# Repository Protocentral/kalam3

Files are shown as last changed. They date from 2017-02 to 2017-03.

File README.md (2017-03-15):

# ProtoCentral Kalam v3 IOT platform

ProtoCentral Kalam v3 is our newest IOT platform based on the ESP8266 Wi-Fi SoC. It's easy-to-use, low cost and easily scalable. 

IoT is now made easy with quick plug-and-play functionality in both hardware and software. Based on the popular ESP8266 Wi-Fi SoC from Espressif, this board contains everything required, right out of the box.

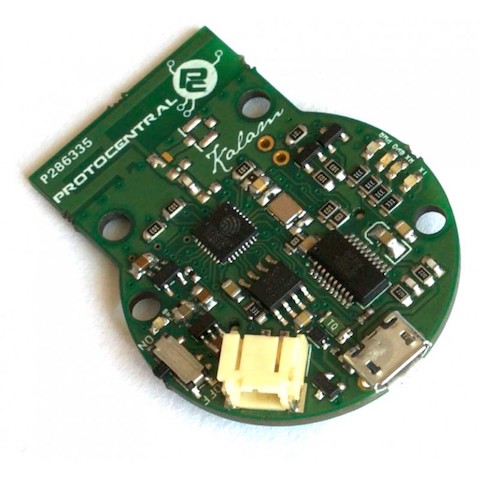
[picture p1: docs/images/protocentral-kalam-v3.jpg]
Kalam v3


Features
--------
* ESP8266EX WiFi System-on-Chip (SoC) with ARM Cortex M3 microcontroller
* On-board 2.4 GHz PCB antenna
* FTDI-based USB-UART interface with microUSB connector
* Fully compatible with the Arduino IDE
* Single Li-Ion battery powered
* On-board battery charger
* 31-pin Hirose DF-9 connector on the back for expansion

Repository Contents
-------------------
* **/hardware** - All Eagle design files (.brd, .sch)
* **/libraries** - Arduino libraries and example code
* **/docs** - Additional Documentation

Board Overview
--------------
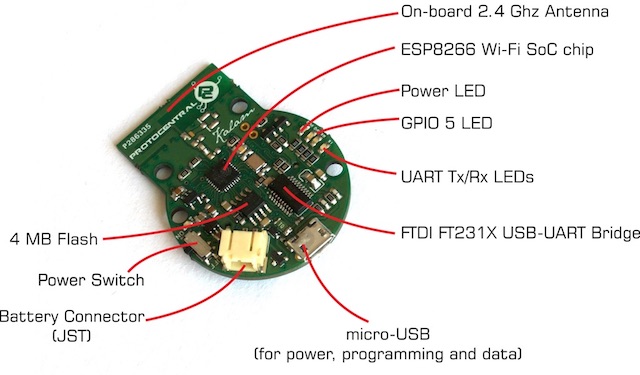
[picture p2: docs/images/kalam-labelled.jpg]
Kalam labelled


Kalam Starter Kit
---------
[Kalam Starter Kit Documentation](docs/starter_kit/README.md)

Getting Started with Kalam
--------------------------

Connect the GPIO expander cap to the Kalam V3 by stacking it on top.Now that the setup is complete,the setup needs to be powered up.Attach a Li-poly battery to the Kalam v2 Iot board.Control the power using the on/off switch

How to setup Arduino support for Kalam (using Sparkfun thing Dev)
---------------------------------------------------
Kalam is powered by the Sparkfun's board support file.The first thing you will need to do is to download the latest release of the Arduino IDE. You will need to be using version 1.6.4 or higher. 
After you have downloaded and installed v1.6.4, you will need to start the IDE and navigate to the Preferences menu.
Sparkfun's  JSON url for ESP8266 board is - https://raw.githubusercontent.com/sparkfun/Arduino_Boards/master/IDE_Board_Manager/package_sparkfun_index.json

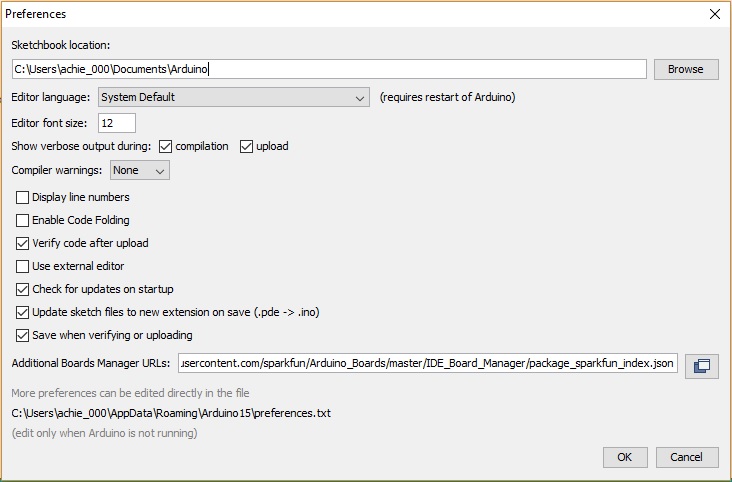
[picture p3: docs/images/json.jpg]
Json


* Click Ok to close and save the preferences
* Then click Tools > Board > Board Manager
* You should find Sparkfun ESP8266 boards listed in the Board Manager window.

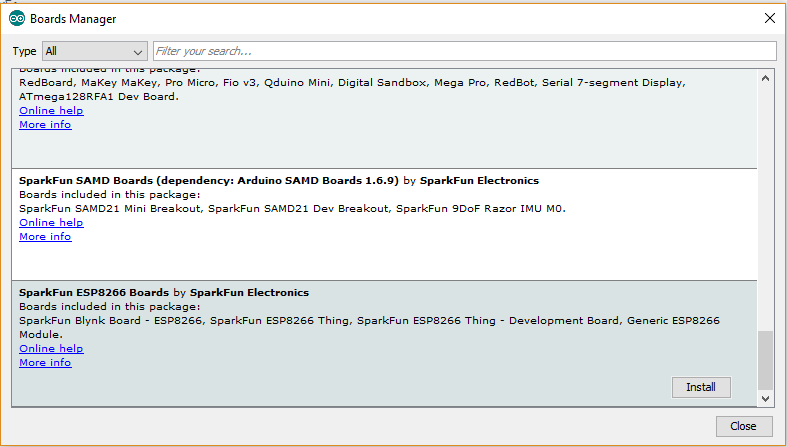
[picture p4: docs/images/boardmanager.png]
board_manager
 
 
*	Press the “Install” button on the chosen ESP8266 category.The download process will begin
* Reboot Arduino and look under Tools > Boards and you should see the addition of the Sparkfun boards in your board list.
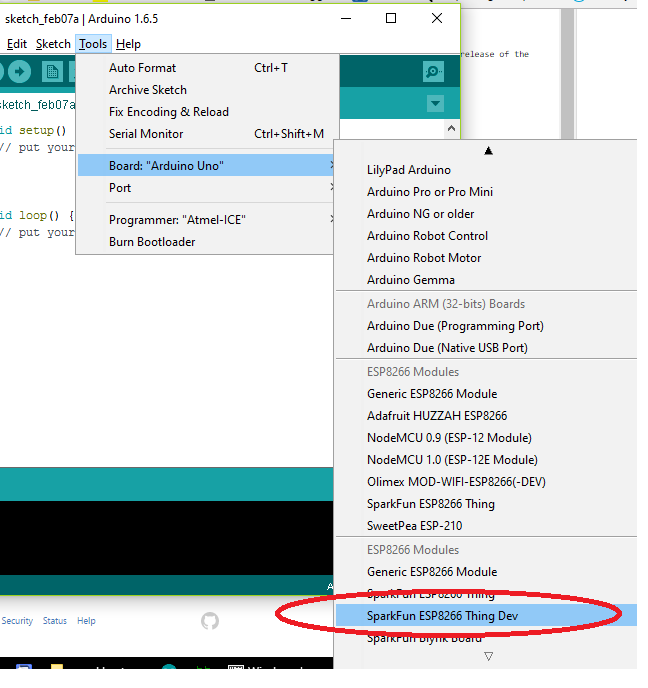
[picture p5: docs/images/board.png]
board


Getting Started with ThingSpeak
-------------------------------
The Internet of Things (IoT) provides access to a broad range of embedded devices and web services. ThingSpeak is an IoT platform that enables you to collect, store, analyze, visualize, and act on data from sensors or actuators.The primary element of ThingSpeak activity is the channel, which contains data fields, location fields, and a status field. After you create a ThingSpeak channel, you can write data to the channel, process and view the data  and react to the data.

Setup ThingSpeak
----------------
ThingSpeak requires a user account and a channel. A channel is where you send data and where ThingSpeak stores data. Each channel has up to 8 data fields, location fields, and a status field. You can send data every 15 seconds to ThingSpeak.

* Sign up for new User Account – https://thingspeak.com/users/sign_up

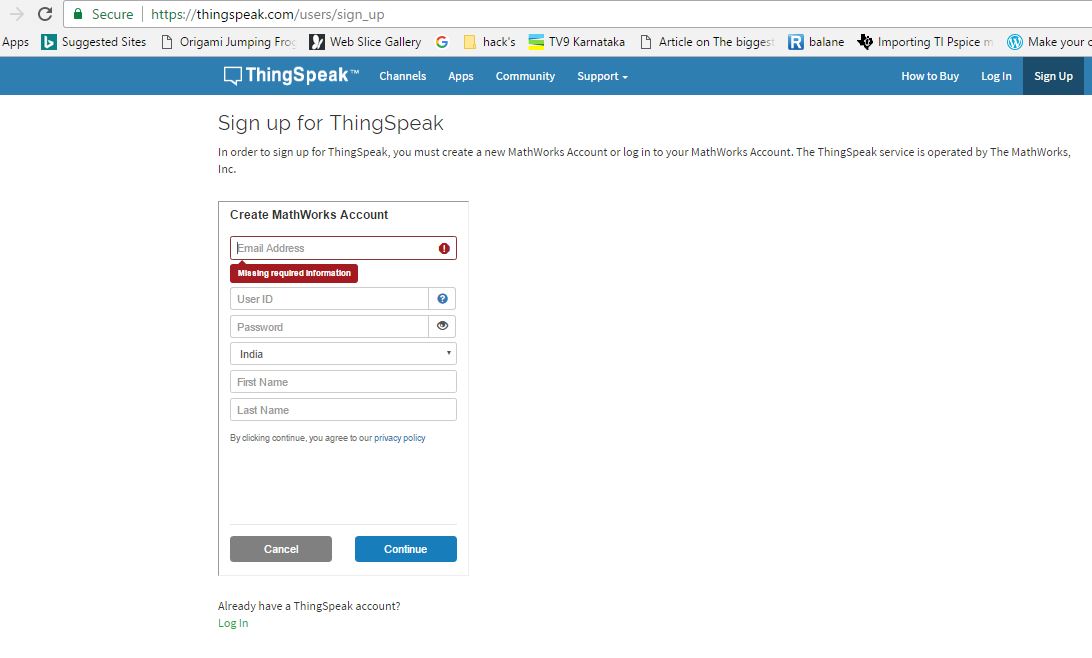
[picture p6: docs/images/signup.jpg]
signup


* Create a new Channel by selecting Channels, My Channels, and then New Channel

newchannel

You can change the name to fit your need and you can add a description corresponding to the channel. You can add any other useful description into the metadata field. In the same page, you should see the fields for Latitude, Longitude and Elevation. Also, you can make the channel as "Private" or "Public".

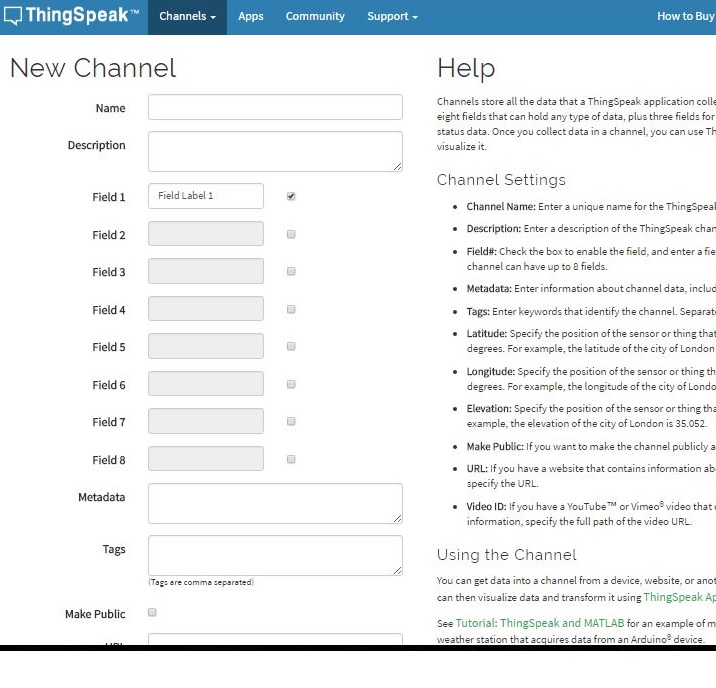
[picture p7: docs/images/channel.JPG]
channel


Once you have edited the fields, click on ‘Save Channel’ button.

Setup Arduino Sketch
--------------------

We have provided a few Arduino sketch examples . They are designed to work right away with no changes.  To make the examples work with your ThingSpeak channel, you will need to configure the myChannelNumber and myWriteAPIKey variables.

  ```
const char* tokenid = "OFZEOKCL95S8HRNI"

  ```
Running a sketch
-----------------------------------
Load the example in the Arduino IDE. Make sure to select the board as "Sparkfun ESP8266 Thing Dev"  and COM port. Then, upload the code to your Kalam.

License Information
-------------------
This product is open source!

Please use, reuse, and modify these files as you see fit. Please maintain attribution to Protocentral and release anything derivative under the same license.

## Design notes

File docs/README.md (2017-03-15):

# ProtoCentral Kalam v3 IOT platform - Starter Kit

# Putting it together

ProtoCentral Kalam v3 is our newest IOT platform based on the ESP8266 Wi-Fi SoC. It's easy-to-use, low cost and easily scalable. 

The new plug-to-play feature allows you to plug-in "modules" to the basic Kalam v3 board to add more functionality such as sensors and actuators.

This documents guides you through the various steps required to put the basic blocks togther and get your first program up and running.

Step 1 - Connecting the boards
--------
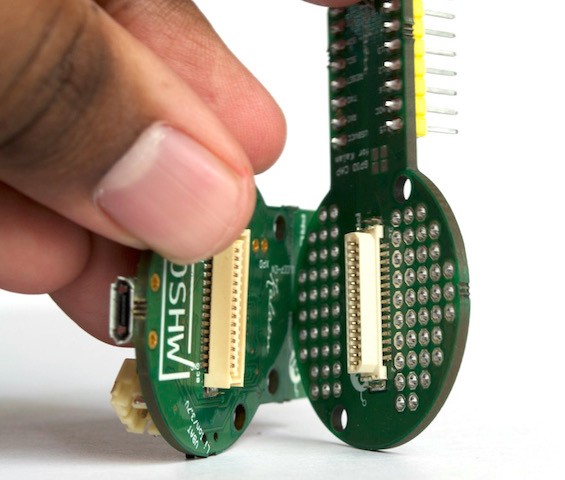
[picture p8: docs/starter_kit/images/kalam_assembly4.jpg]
Kalam Assembly-Step 1


Take the Kalam v3 main board and the GPIO cap provided in the kit. On the reverse side of each board, you will find a white 31-pin connector that mates with the other. Gently put it together and then press firmly to get a good fit. The connectors only go in one way, so make sure to align them properly. The connectors should align up with each other as shown in the below picture.

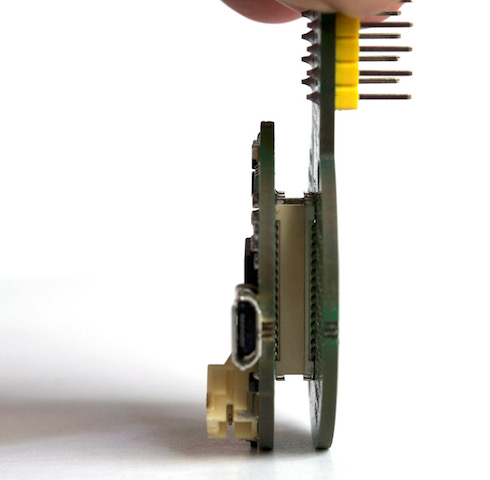
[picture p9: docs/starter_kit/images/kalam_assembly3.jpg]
Kalam Assembly-Step 1


Step 2 - Connect the battery
-------------------

If you have purchased Kalam as a kit and you have a Li-Ion battery included, connect the battery to the white JST connector on the board as shown below. 

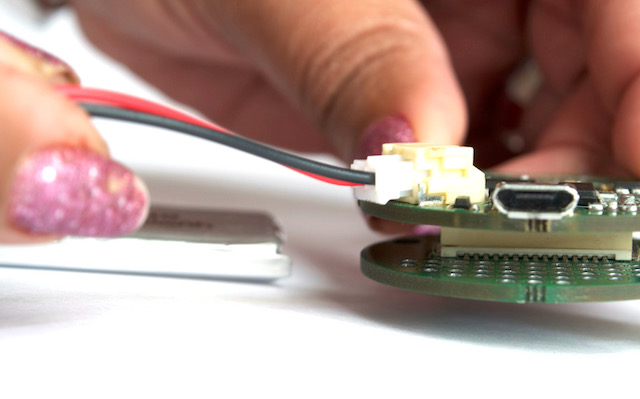
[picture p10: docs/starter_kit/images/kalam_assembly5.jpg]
Kalam Assembly-Step 2


This connector will also go in only one way. Please note the direction in which it is to be inserted.

If you purchased the Kalam board separately and a battery was not included, you can use it with any 3.7V Li-Ion/Li-Poly battery with a JST connector. ***Ensure that the connector has the proper polarity before connecting any external battery pack.***

Step 3 - Plugging it into a breadboard (optional)
-----------------

If you have a breadboard, you can now directly plug in the entire assembly into a standard breadboard and it should now be ready for prototyping

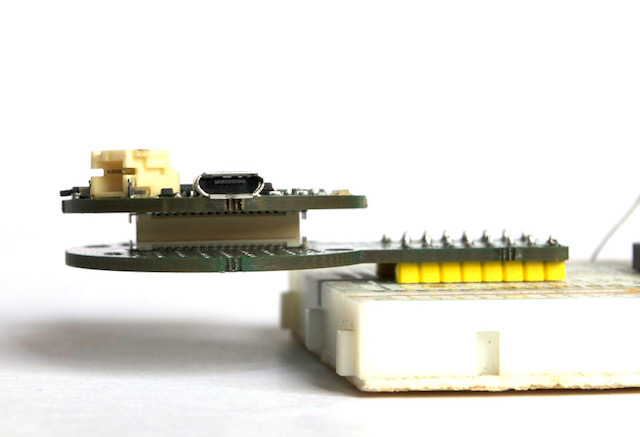
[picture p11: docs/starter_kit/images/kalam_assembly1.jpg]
Kalam Assembly-Step 3


Step 4 - Setting up Arduino for Kalam
----------------------------

Kalam is powered by the Sparkfun's board support file.The first thing you will need to do is to download the latest release of the Arduino IDE. You will need to be using version 1.6.4 or higher. 
After you have downloaded and installed v1.6.4, you will need to start the IDE and navigate to the Preferences menu.
Sparkfun's  JSON url for ESP8266 board is - https://raw.githubusercontent.com/sparkfun/Arduino_Boards/master/IDE_Board_Manager/package_sparkfun_index.json

Json

* Click Ok to close and save the preferences
* Then click Tools > Board > Board Manager
* You should find Sparkfun ESP8266 boards listed in the Board Manager window.

 board_manager
 
*	Press the “Install” button on the chosen ESP8266 category.The download process will begin
* Reboot Arduino and look under Tools > Boards and you should see the addition of the Sparkfun boards in your board list.
board

Step 5 - Setting up ThingSpeak
-------------------------------
The Internet of Things (IoT) provides access to a broad range of embedded devices and web services. ThingSpeak is an IoT platform that enables you to collect, store, analyze, visualize, and act on data from sensors or actuators.The primary element of ThingSpeak activity is the channel, which contains data fields, location fields, and a status field. After you create a ThingSpeak channel, you can write data to the channel, process and view the data  and react to the data.

### Sign-up for ThingSpeak

ThingSpeak requires a user account and a channel. A channel is where you send data and where ThingSpeak stores data. Each channel has up to 8 data fields, location fields, and a status field. You can send data every 15 seconds to ThingSpeak.

* Sign up for new User Account – https://thingspeak.com/users/sign_up

signup

* Create a new Channel by selecting Channels, My Channels, and then New Channel

newchannel

You can change the name to fit your need and you can add a description corresponding to the channel. You can add any other useful description into the metadata field. In the same page, you should see the fields for Latitude, Longitude and Elevation. Also, you can make the channel as "Private" or "Public".

channel

Once you have edited the fields, click on ‘Save Channel’ button.

Setup Arduino Sketch
--------------------

We have provided a few Arduino sketch examples . They are designed to work right away with no changes.  To make the examples work with your ThingSpeak channel, you will need to configure the myChannelNumber and myWriteAPIKey variables.

  ```
const char* tokenid = "OFZEOKCL95S8HRNI"

  ```
Running a sketch
----------------
Load the example in the Arduino IDE. Make sure to select the board as "Sparkfun ESP8266 Thing Dev"  and COM port. Then, upload the code to your Kalam.

License Information
-------------------
This product is open source!

Please use, reuse, and modify these files as you see fit. Please maintain attribution to Protocentral and release anything derivative under the same license.

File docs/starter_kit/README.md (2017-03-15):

# ProtoCentral Kalam v3 IOT platform - Starter Kit
------------------
This kit includes all the basic components required to get your Kalam-based IoT project up and running.

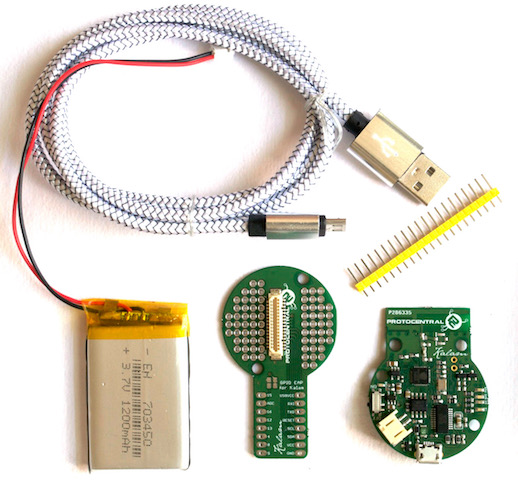
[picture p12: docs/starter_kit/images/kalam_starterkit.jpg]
Kalam Starter Kit


# Kit Contents:

* 1x Kalam v3 IoT board
* 1x GPIO cap for Kalam v3 platform
* 1x 3.7V, 1200 mAH Li-Poly battery (only for orders within India)
* 1x micro-USB cable
* 1x breakaway header-20 pins

# Putting it together

ProtoCentral Kalam v3 is our newest IOT platform based on the ESP8266 Wi-Fi SoC. It's easy-to-use, low cost and easily scalable. 

The new plug-to-play feature allows you to plug-in "modules" to the basic Kalam v3 board to add more functionality such as sensors and actuators.

This documents guides you through the various steps required to put the basic blocks togther and get your first program up and running.

Step 1 - Connecting the boards
--------
Kalam Assembly-Step 1

Take the Kalam v3 main board and the GPIO cap provided in the kit. On the reverse side of each board, you will find a white 31-pin connector that mates with the other. Gently put it together and then press firmly to get a good fit. The connectors only go in one way, so make sure to align them properly. The connectors should align up with each other as shown in the below picture.

Kalam Assembly-Step 1

Step 2 - Connect the battery
-------------------

If you have purchased Kalam as a kit and you have a Li-Ion battery included, connect the battery to the white JST connector on the board as shown below. 

Kalam Assembly-Step 2

This connector will also go in only one way. Please note the direction in which it is to be inserted.

If you purchased the Kalam board separately and a battery was not included, you can use it with any 3.7V Li-Ion/Li-Poly battery with a JST connector. ***Ensure that the connector has the proper polarity before connecting any external battery pack.***

Step 3 - Plugging it into a breadboard (optional)
-----------------

If you have a breadboard, you can now directly plug in the entire assembly into a standard breadboard and it should now be ready for prototyping

Kalam Assembly-Step 3

Step 4 - Setting up Arduino for Kalam
----------------------------

Kalam is powered by the Sparkfun's board support file.The first thing you will need to do is to download the latest release of the Arduino IDE. You will need to be using version 1.6.4 or higher. 
After you have downloaded and installed v1.6.4, you will need to start the IDE and navigate to the Preferences menu.
Sparkfun's  JSON url for ESP8266 board is - https://raw.githubusercontent.com/sparkfun/Arduino_Boards/master/IDE_Board_Manager/package_sparkfun_index.json

Json

* Click Ok to close and save the preferences
* Then click Tools > Board > Board Manager
* You should find Sparkfun ESP8266 boards listed in the Board Manager window.

 board_manager
 
*	Press the “Install” button on the chosen ESP8266 category.The download process will begin
* Reboot Arduino and look under Tools > Boards and you should see the addition of the Sparkfun boards in your board list.
board

Step 5 - Setting up ThingSpeak
-------------------------------
The Internet of Things (IoT) provides access to a broad range of embedded devices and web services. ThingSpeak is an IoT platform that enables you to collect, store, analyze, visualize, and act on data from sensors or actuators.The primary element of ThingSpeak activity is the channel, which contains data fields, location fields, and a status field. After you create a ThingSpeak channel, you can write data to the channel, process and view the data  and react to the data.

### Sign-up for ThingSpeak

ThingSpeak requires a user account and a channel. A channel is where you send data and where ThingSpeak stores data. Each channel has up to 8 data fields, location fields, and a status field. You can send data every 15 seconds to ThingSpeak.

* Sign up for new User Account – https://thingspeak.com/users/sign_up

signup

* Create a new Channel by selecting Channels, My Channels, and then New Channel

newchannel

You can change the name to fit your need and you can add a description corresponding to the channel. You can add any other useful description into the metadata field. In the same page, you should see the fields for Latitude, Longitude and Elevation. Also, you can make the channel as "Private" or "Public".

channel

Once you have edited the fields, click on ‘Save Channel’ button.

### Running The skecth

* Step1: Plug-in the Kalam to the Computer throughthe micro-USB cable provided.
* Step2: Kalam board got a on board FT231 which is a USB to UART bridge for the uploading the sketch
* Step3: Your system has to automaticlly install the FTDI drivers and it shows up as a vertual COM port.  You can go to the Windows     Device Manager and look under Ports(COM & LPT) to find out the COM port number for the installed device.

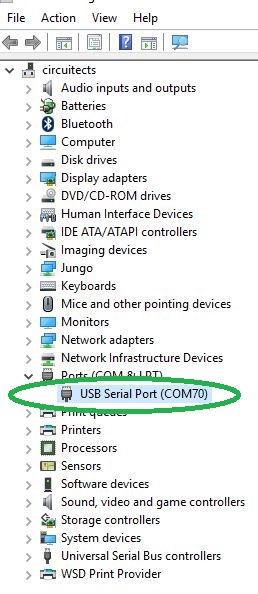
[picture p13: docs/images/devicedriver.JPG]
device driver


###Note:If you've never used an FTDI device, you may need to install drivers on your computer before you can program the Kalam.For installation please checkout this tutorials from Sparkfun -- https://learn.sparkfun.com/tutorials/how-to-install-ftdi-drivers/windows---quick-and-easy
 
 Blink
 ------
We have provided a few Arduino sketch examples . They are designed to work right away with no changes. 
This example shows the simplest thing you can do with an Kalam to see physical output: it blinks the on-board LED.
Open the Arduino IDE, load the example skecth provided example --> basicBlink. Make sure to select the board as "Sparkfun ESP8266 Thing Dev"  and COM port. Then, upload the code to your Kalam., now on board LED will blink for every one second.
define the PIN number:
```sh
#define LED_PIN   5  
```
Simple Thingspeak Post
------------------------
This exampleconnects to the internet via your local wireless Router and updates the data on to the thingspeak channel. You ned 
Configure Wifi network:
```sh
const char* ssid     = "********";  // your network id
const char* password = "*********";  // passcode
```
To make the examples work with your ThingSpeak channel, you will need to configure the myChannelNumber and myWriteAPIKey variables.
Token ID:
```
const char* tokenid = "OFZEOKCL95S8HRNI"; // your channel token id

```

License Information
-------------------
This product is open source!

Please use, reuse, and modify these files as you see fit. Please maintain attribution to Protocentral and release anything derivative under the same license.

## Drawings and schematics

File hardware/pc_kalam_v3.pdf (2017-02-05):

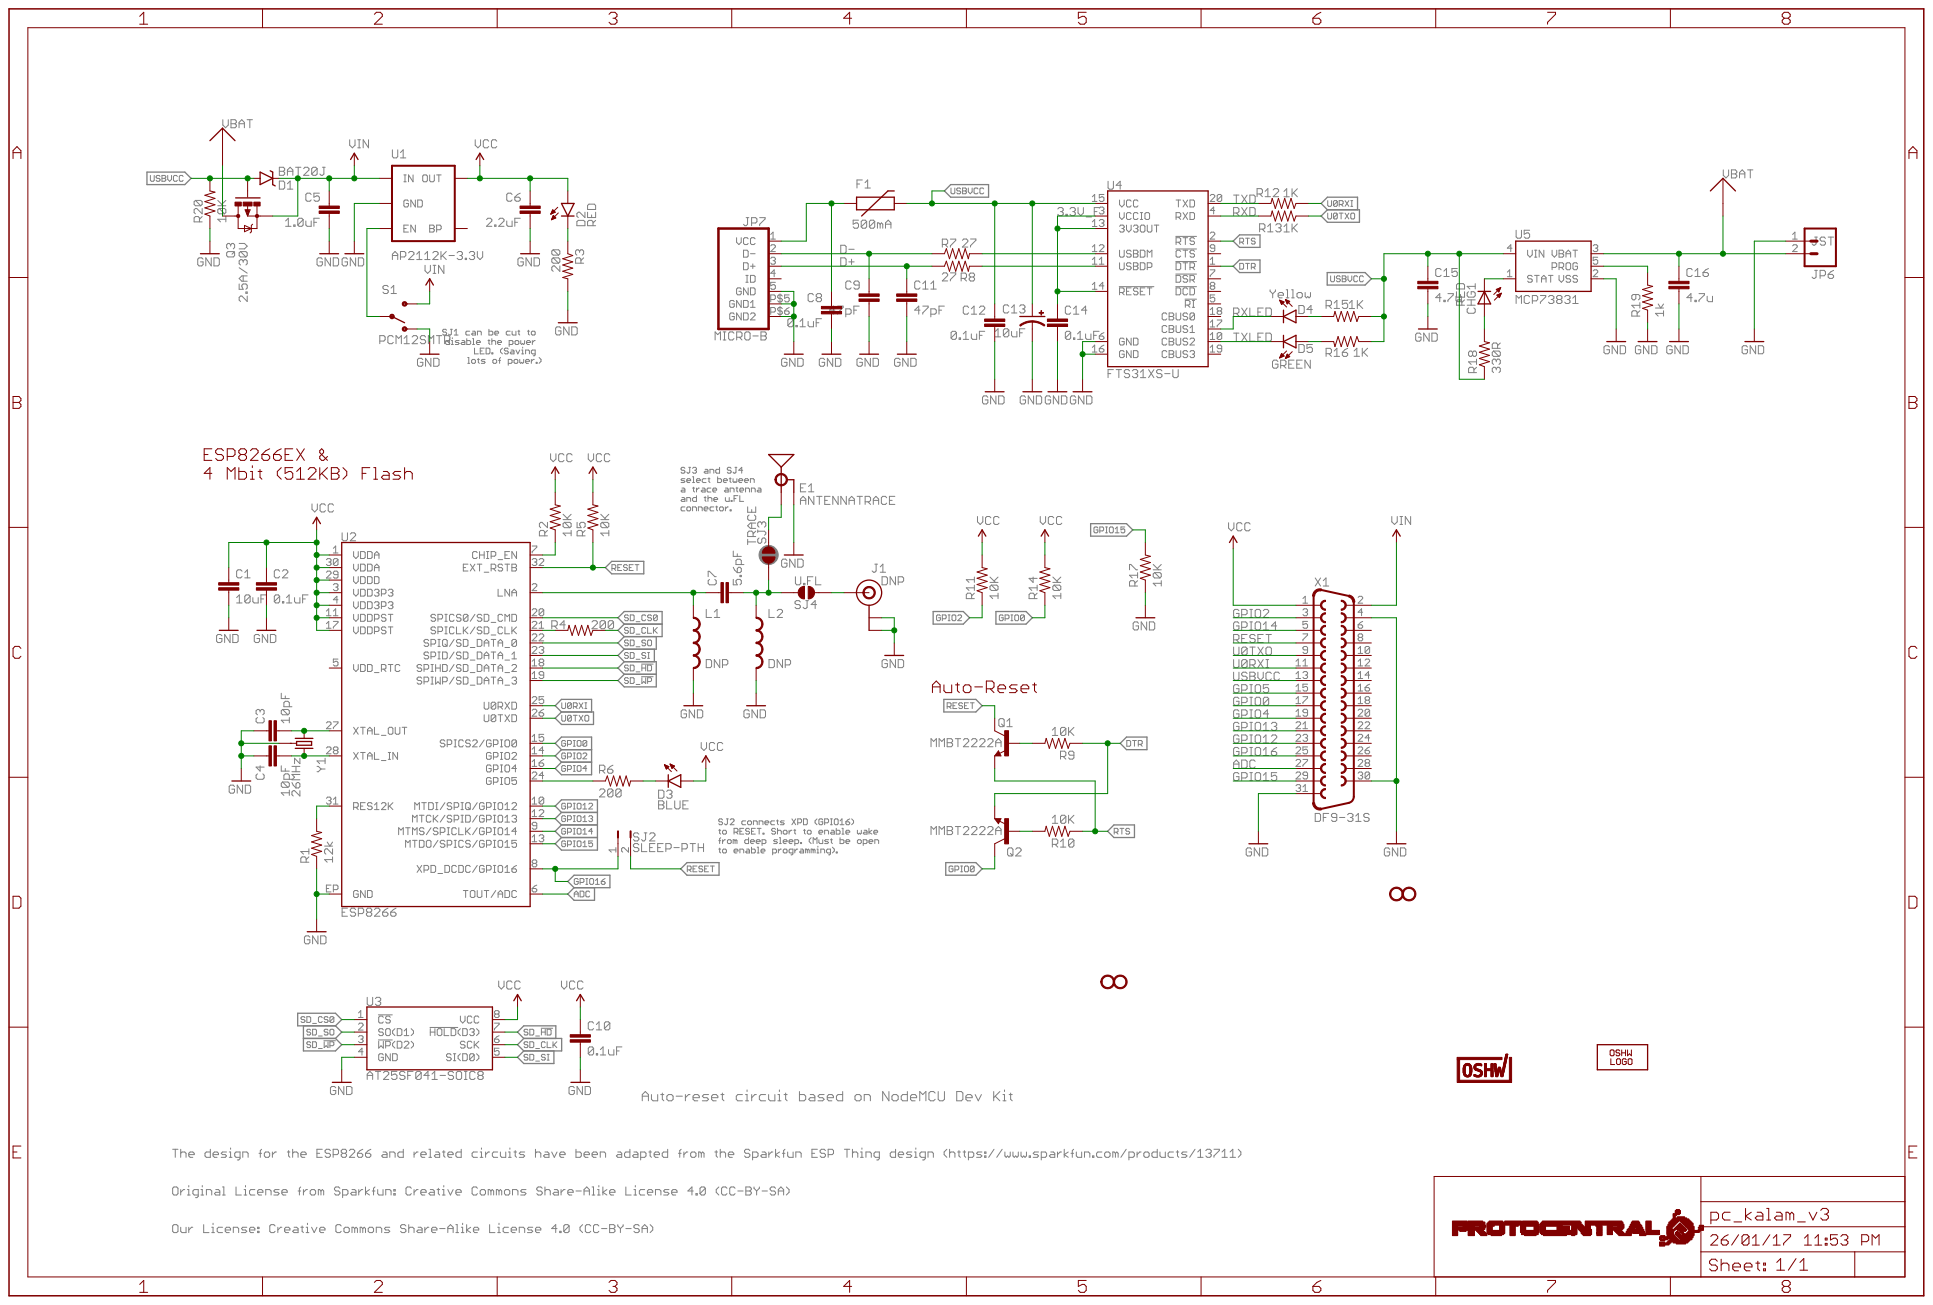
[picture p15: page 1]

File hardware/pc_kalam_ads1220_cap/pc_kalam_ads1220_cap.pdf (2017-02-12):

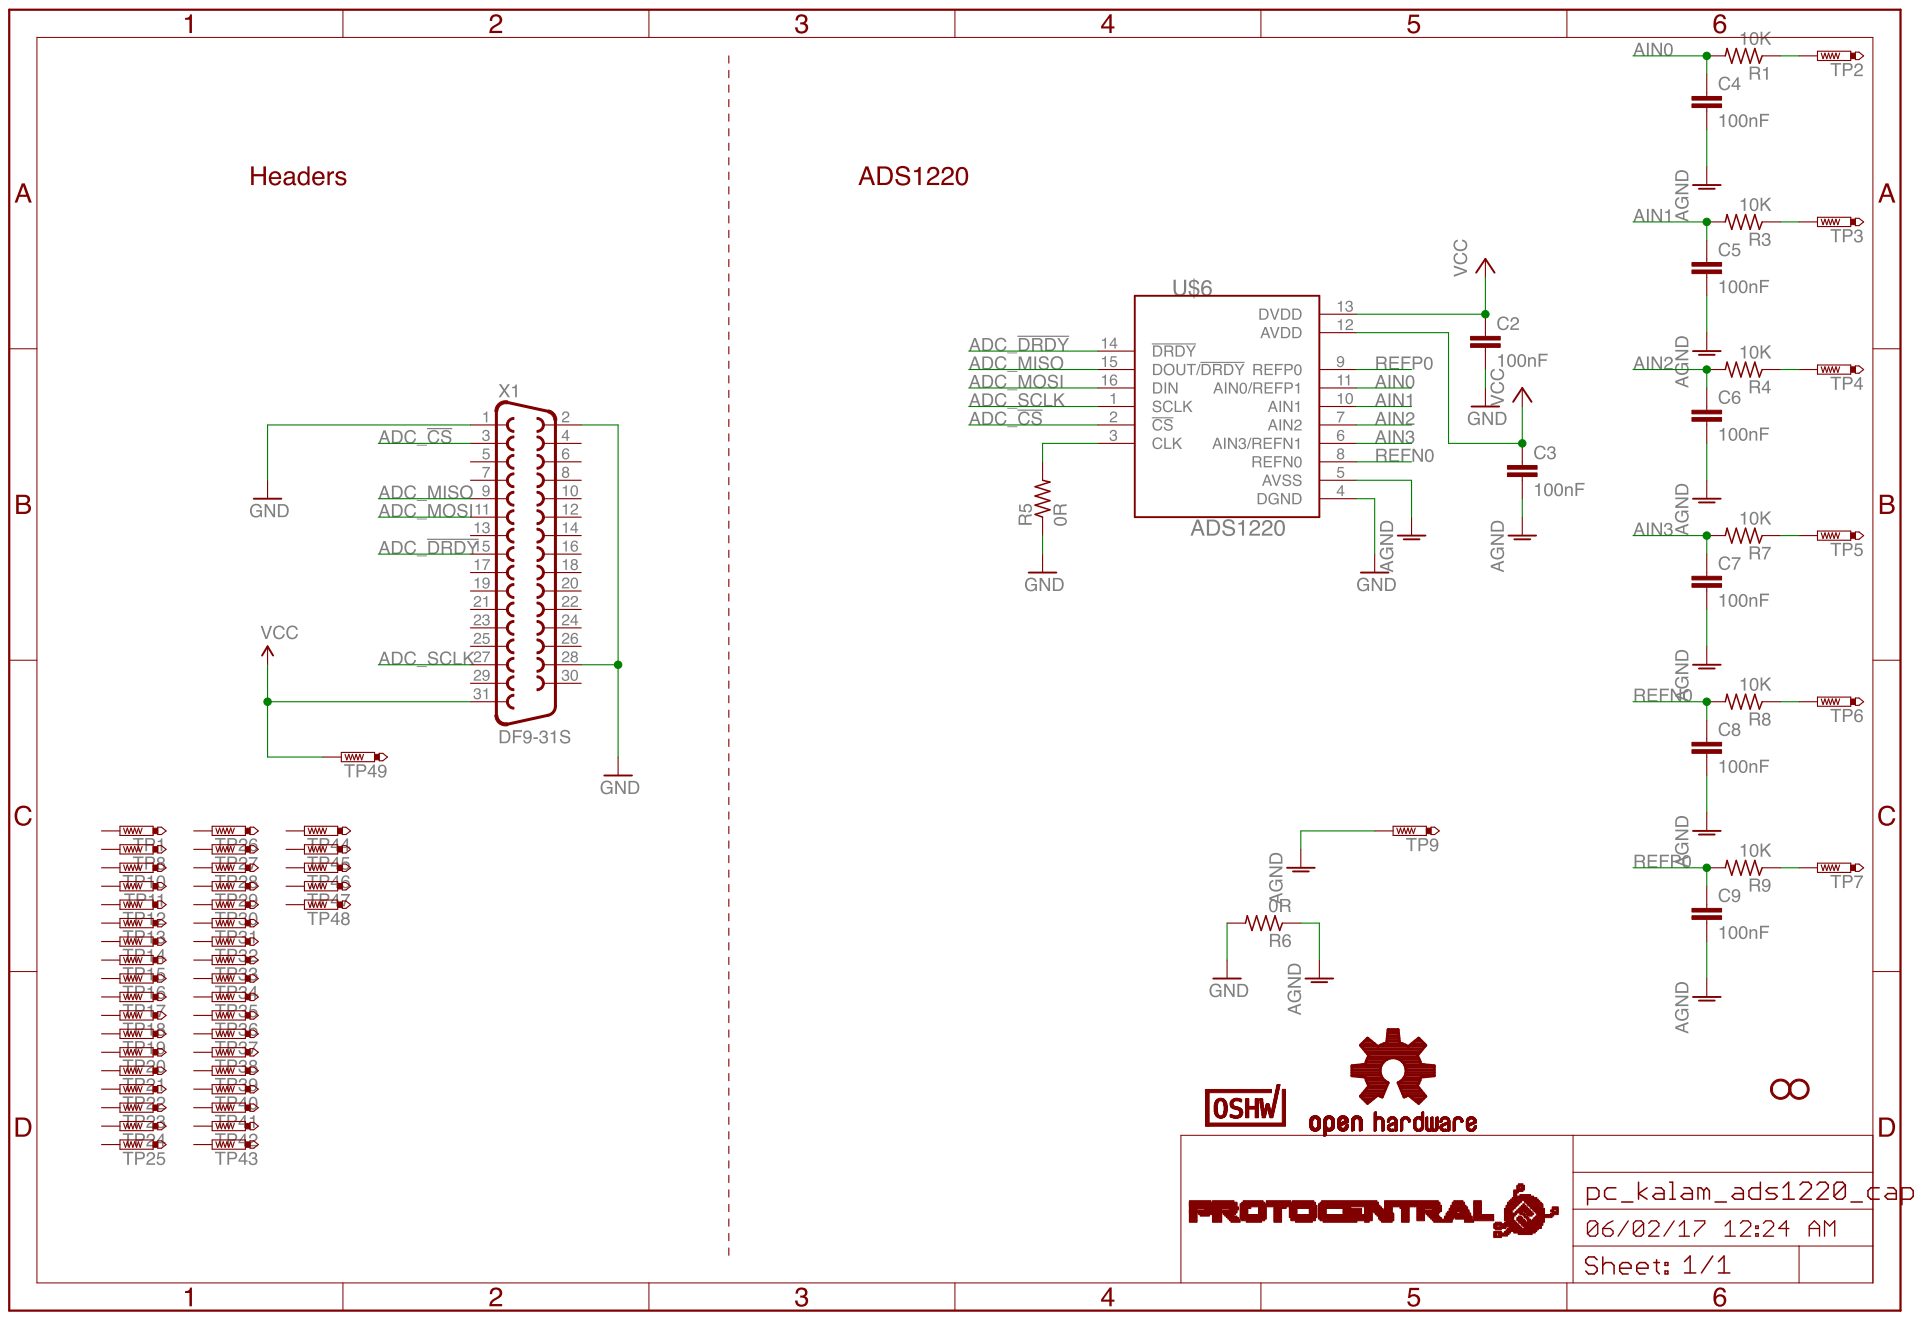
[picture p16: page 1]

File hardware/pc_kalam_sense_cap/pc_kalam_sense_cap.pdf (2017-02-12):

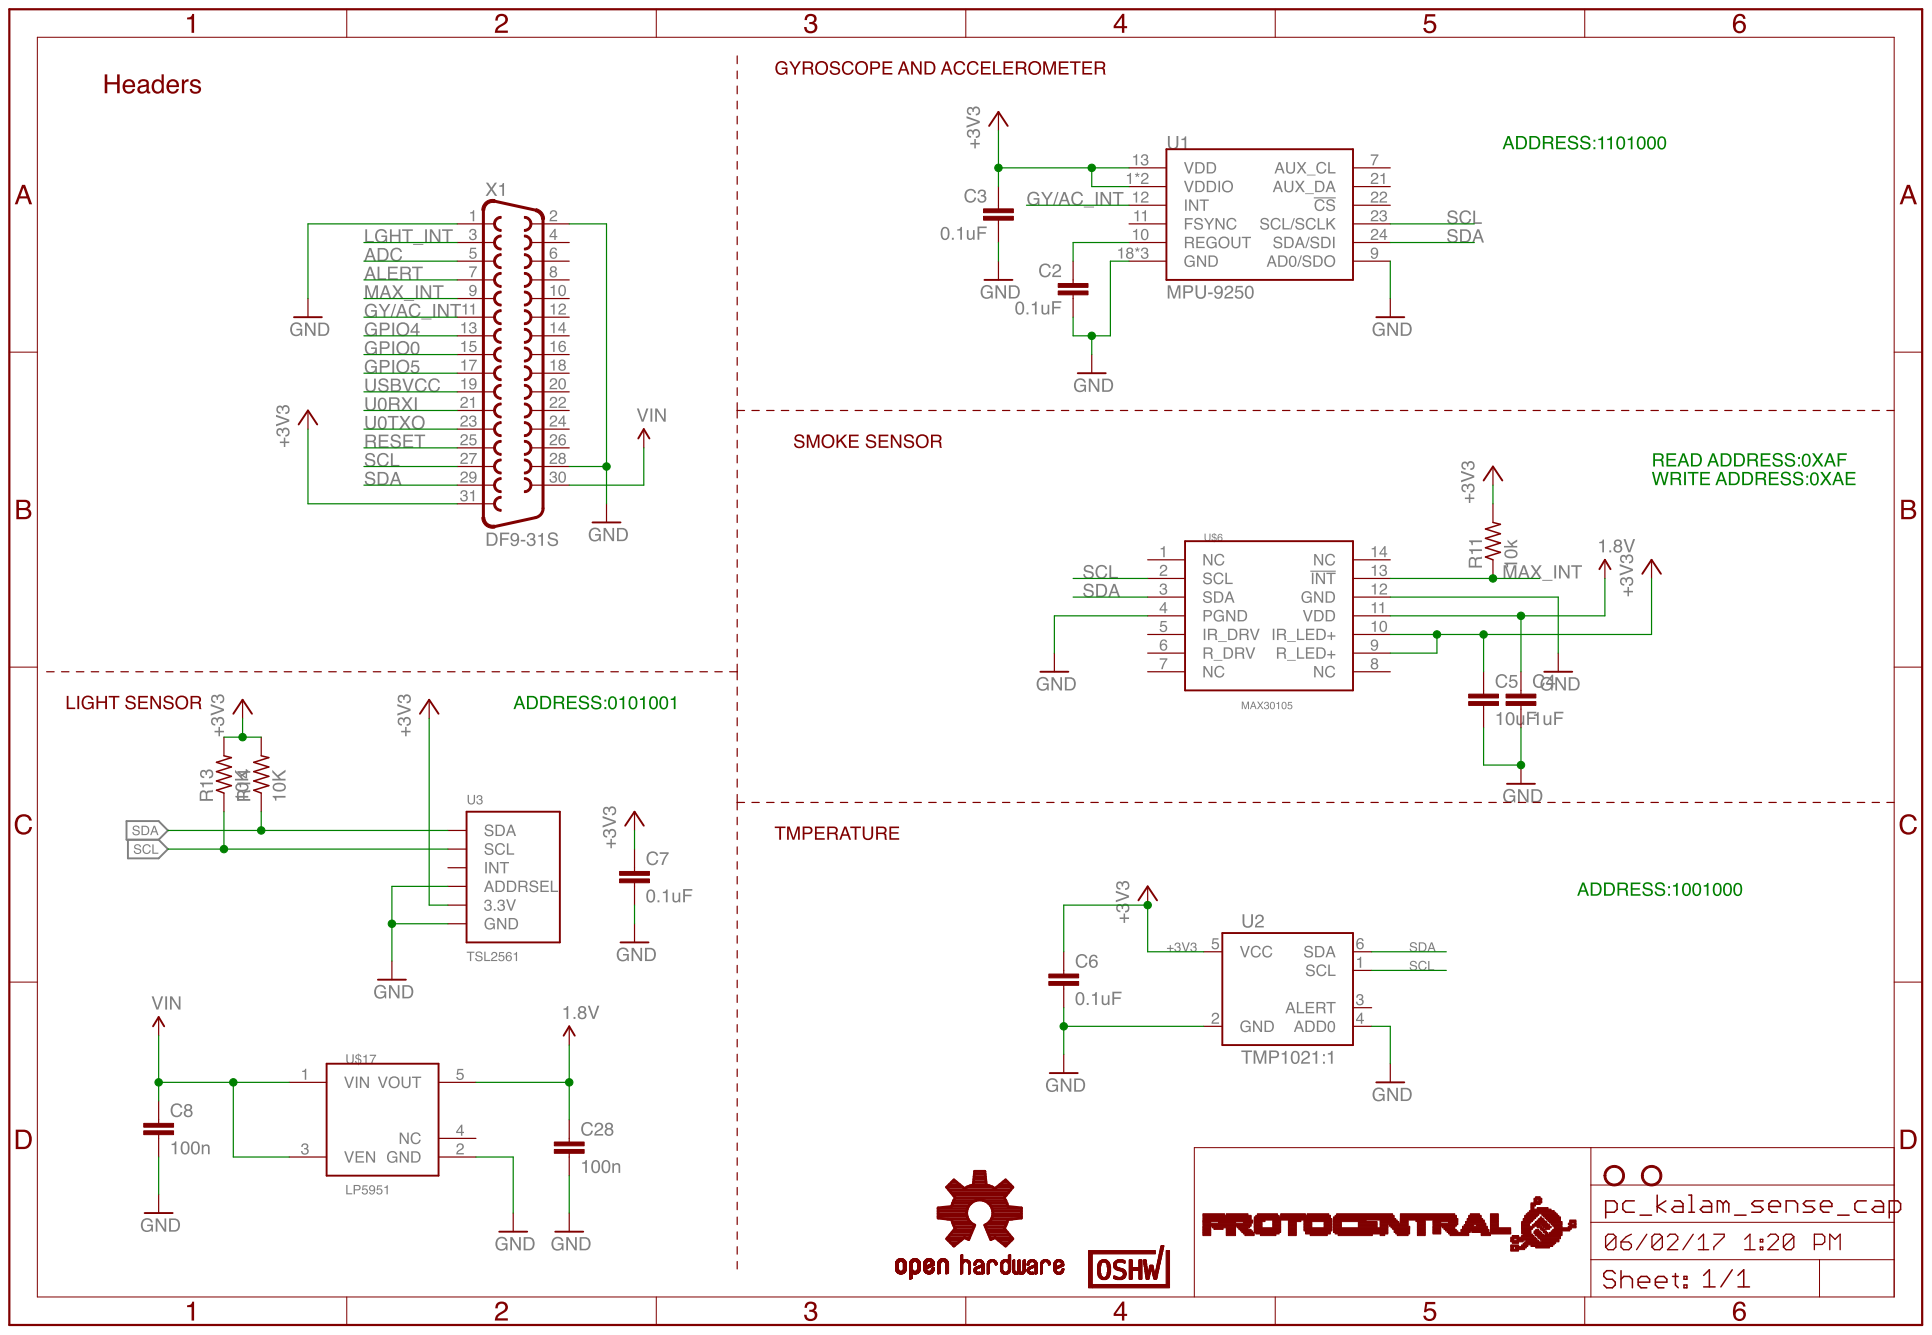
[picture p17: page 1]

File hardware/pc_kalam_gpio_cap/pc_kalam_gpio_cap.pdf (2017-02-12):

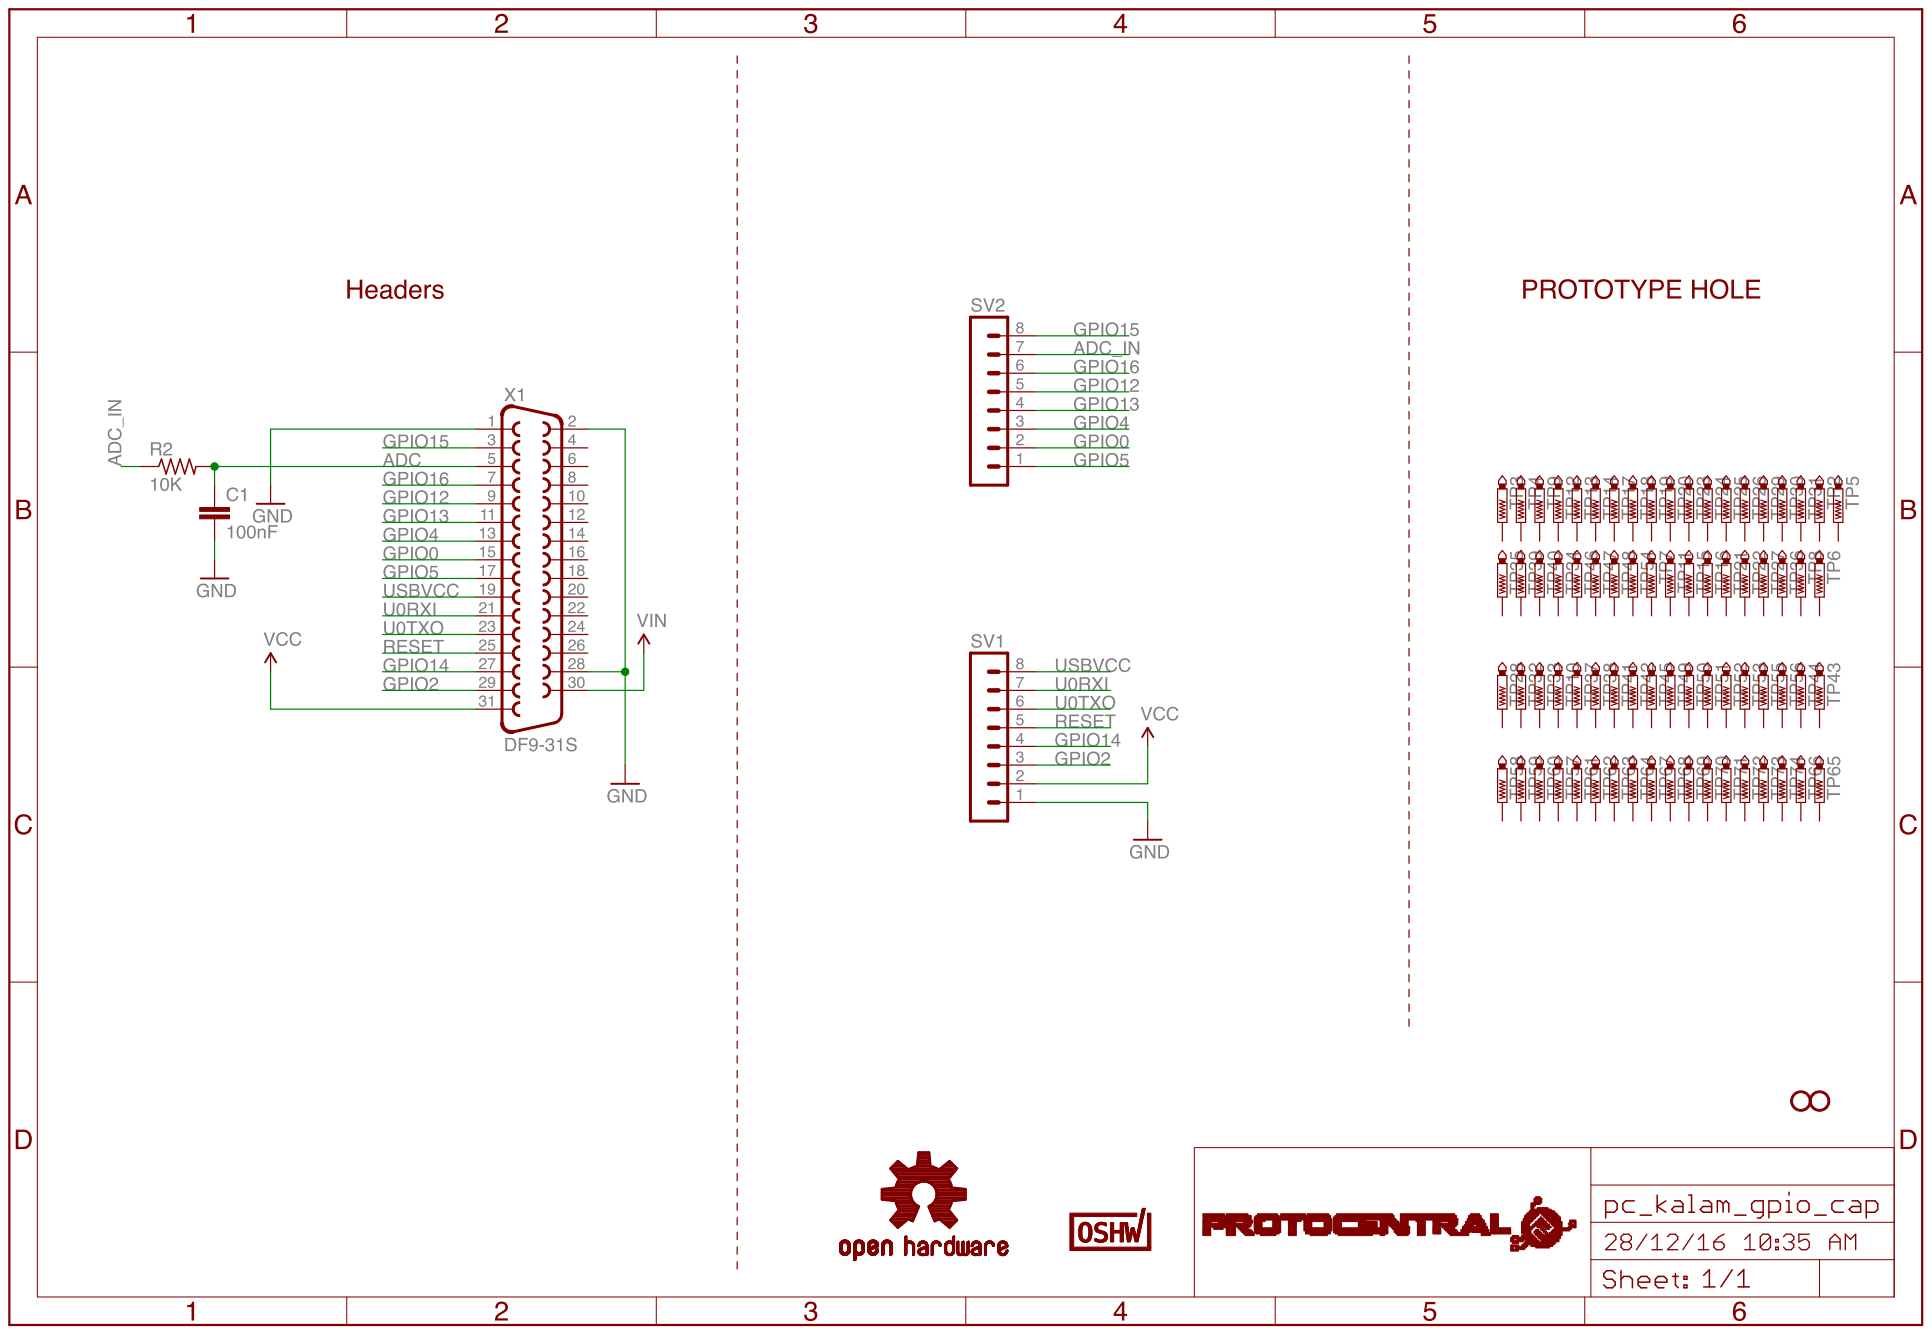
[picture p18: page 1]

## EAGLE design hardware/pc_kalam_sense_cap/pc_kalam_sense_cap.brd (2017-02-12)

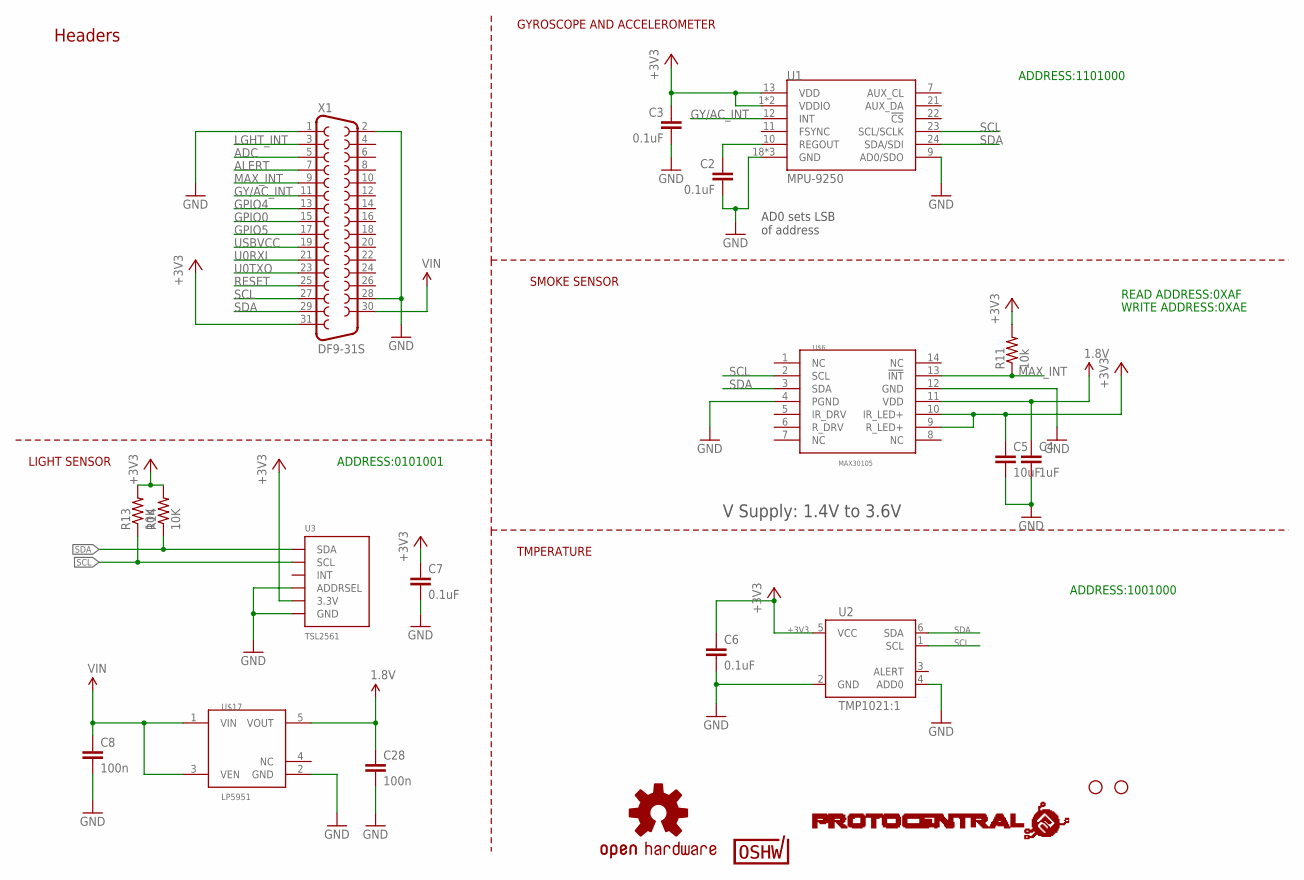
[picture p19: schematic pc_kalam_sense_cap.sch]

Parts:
C2, C3, C6: 0.1uF; 0603-CAP
C4: 1uF; C0805
C5: 10uF; C0805
C7: 0.1uF; C0805
C8, C28: 100n; C0402
R11: 10k; R0402
R13, R14: 10K; R0805
STANDOFF7, STANDOFF8: STAND-OFF
U1: MPU-9250; QFN24_PAD
U2: TMP1021:1; SOT563-2
U3: TSL2561; TSL2561_FN
U$2: CERT-SMALL; CERT-SMALL-SILK
U$3: OSHW-LOGOS; OSHW-LOGO-S
U$6: MAX30105; OESIP-14
U$9: PROTY_LOGO_WITH_TEXT; PROTY_WITH_TEXT
U$17: LP5951; SC70-5
X1: DF9-31S

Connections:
1.8V: C4.1, C28.1, U$6.11 (VDD), U$17.5 (VOUT)
+3V3: C3.1, C5.1, C6.1, C7.1, R11.2, R13.2, R14.2, U1.1 (VDDIO), U1.8 (VDDIO), U1.13 (VDD), U2.5 (VCC), U3.VDD (3.3V), U$6.9 (R_LED+), U$6.10 (IR_LED+), X1.31
ADC: X1.5
ALERT: X1.7
GND: C2.2, C3.2, C4.2, C5.2, C6.2, C7.2, C8.2, C28.2, U1.9 (AD0/SDO), U1.18 (GND), U1.20 (GND), U1.CENTER (GND), U2.2 (GND), U2.4 (ADD0), U3.ADR (ADDRSEL), U3.VSS (GND), U$6.4 (PGND), U$6.12 (GND), U$17.2 (GND), X1.1, X1.2, X1.28
GPIO0: X1.15
GPIO4: X1.13
GPIO5: X1.17
GY/AC_INT: U1.12 (INT), X1.11
LGHT_INT: X1.3
MAX_INT: R11.1, U$6.13 (!INT), X1.9
REGOUT: C2.1, U1.10 (REGOUT)
RESET: X1.25
SCL: R13.1, U1.23 (SCL/SCLK), U2.1 (SCL), U3.CLK (SCL), U$6.2 (SCL), X1.27
SDA: R14.1, U1.24 (SDA/SDI), U2.6 (SDA), U3.DATA (SDA), U$6.3 (SDA), X1.29
U0RXI: X1.21
U0TXO: X1.23
USBVCC: X1.19
VIN: C8.1, U$17.1 (VIN), U$17.3 (VEN), X1.30

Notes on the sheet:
Headers
AD0 sets LSB of address
V Supply: 1.4V to 3.6V
TMPERATURE
SMOKE SENSOR
GYROSCOPE AND ACCELEROMETER
LIGHT SENSOR
ADDRESS:1101000
ADDRESS:1001000
ADDRESS:0101001
READ ADDRESS:0XAF
WRITE ADDRESS:0XAE

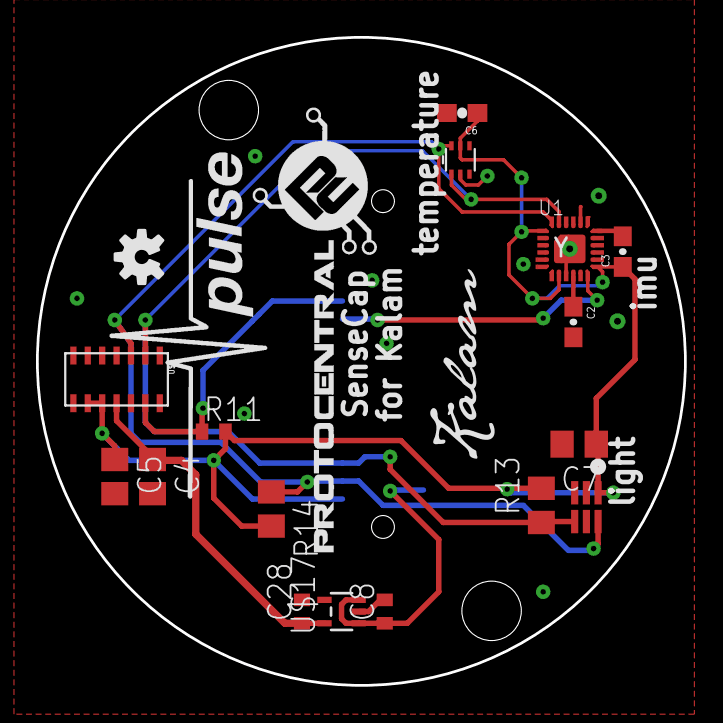
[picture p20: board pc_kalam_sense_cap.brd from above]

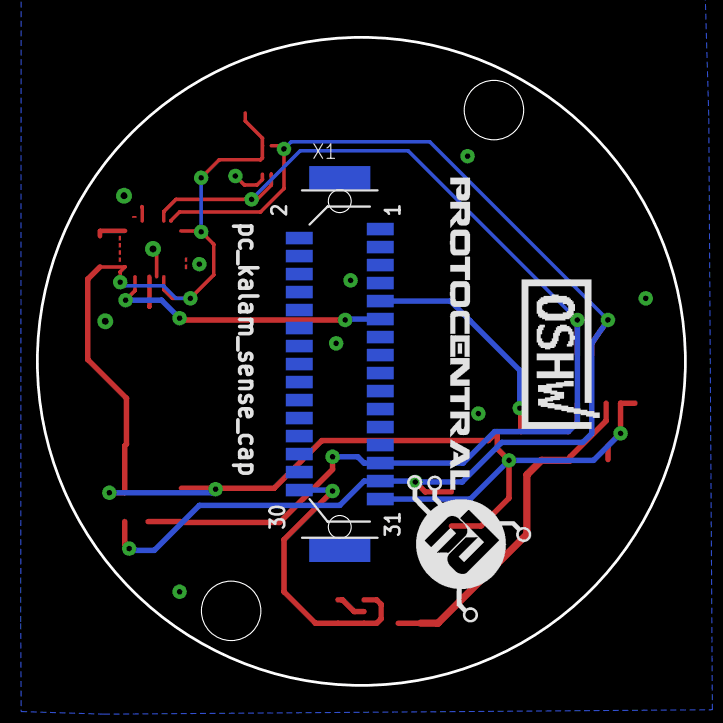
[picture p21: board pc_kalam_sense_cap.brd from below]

Board: 4 copper layers, 36.0 x 36.0 mm, 25 parts (5 on the bottom side), 9 nets.

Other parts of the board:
U$1: PULSE
U$4: KALAM-NAME-ONLY
U$5: PROTY_LOGO_WITH_TEXT; PROTY_WITH_TEXT

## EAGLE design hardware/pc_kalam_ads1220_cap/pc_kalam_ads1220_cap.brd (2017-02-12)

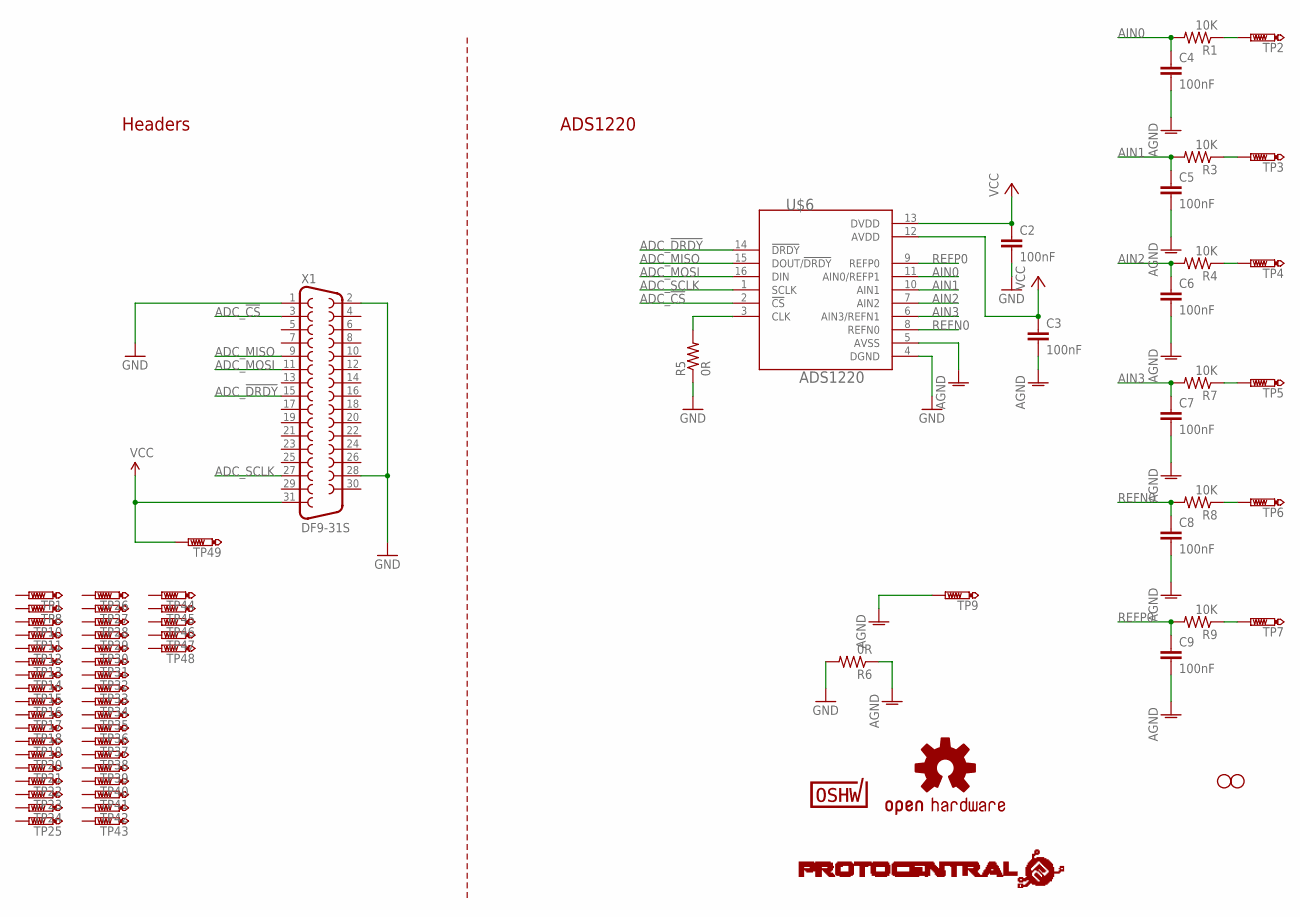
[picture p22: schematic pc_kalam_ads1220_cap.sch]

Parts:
C2, C3, C4, C5, C6, C7, C8, C9: 100nF; C0805
R1, R3, R4, R7, R8, R9: 10K; R0805
R5, R6: 0R; R0805
STANDOFF7, STANDOFF8: STAND-OFF
TP1, TP2, TP3, TP4, TP5, TP6, TP7, TP8, TP9, TP10, TP11, TP12, TP13, TP14, TP15, TP16, TP17, TP18, TP19, TP20, TP21, TP22, TP23, TP24, TP25, TP26, TP27, TP28, TP29, TP30, TP31, TP32, TP33, TP34, TP35, TP36, TP37, TP38, TP39, TP40, TP41, TP42, TP43, TP44, TP45, TP46, TP47, TP48, TP49: PTR1PAD1-13; P1-13
U$1: PROTY-LOGO; LOGO-PROTY
U$2: CERT-SMALL; CERT-SMALL-SILK
U$3: OSHW-LOGOS; OSHW-LOGO-S
U$6: ADS1220; TSSOP-16
X1: DF9-31S

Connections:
ADC_!CS: U$6.2 (!CS), X1.3
ADC_!DRDY: U$6.14 (!DRDY), X1.15
ADC_CLK: R5.2, U$6.3 (CLK)
ADC_MISO: U$6.15 (DOUT/!DRDY), X1.9
ADC_MOSI: U$6.16 (DIN), X1.11
ADC_SCLK: U$6.1 (SCLK), X1.27
AGND: C3.2, C4.2, C5.2, C6.2, C7.2, C8.2, C9.2, R6.1, TP9.TP, U$6.5 (AVSS)
AIN0: C4.1, R1.2, U$6.11 (AIN0/REFP1)
AIN1: C5.1, R3.2, U$6.10 (AIN1)
AIN2: C6.1, R4.2, U$6.7 (AIN2)
AIN3: C7.1, R7.2, U$6.6 (AIN3/REFN1)
GND: C2.2, R5.1, R6.2, U$6.4 (DGND), X1.1, X1.2, X1.28
unnamed: R1.1, TP2.TP
unnamed: R3.1, TP3.TP
unnamed: R4.1, TP4.TP
unnamed: R7.1, TP5.TP
unnamed: R8.1, TP6.TP
unnamed: R9.1, TP7.TP
REFN0: C8.1, R8.2, U$6.8 (REFN0)
REFP0: C9.1, R9.2, U$6.9 (REFP0)
VCC: C2.1, C3.1, TP49.TP, U$6.12 (AVDD), U$6.13 (DVDD), X1.31

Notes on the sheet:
Headers
ADS1220

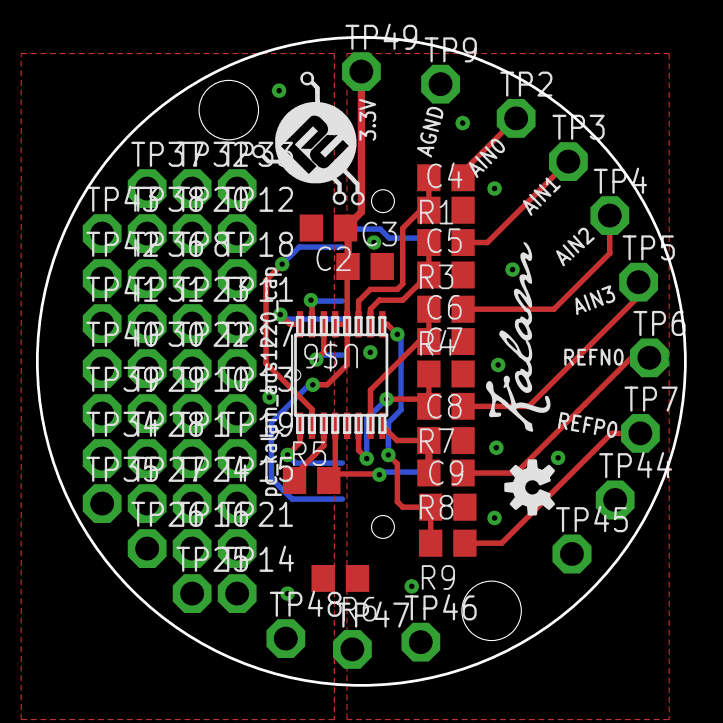
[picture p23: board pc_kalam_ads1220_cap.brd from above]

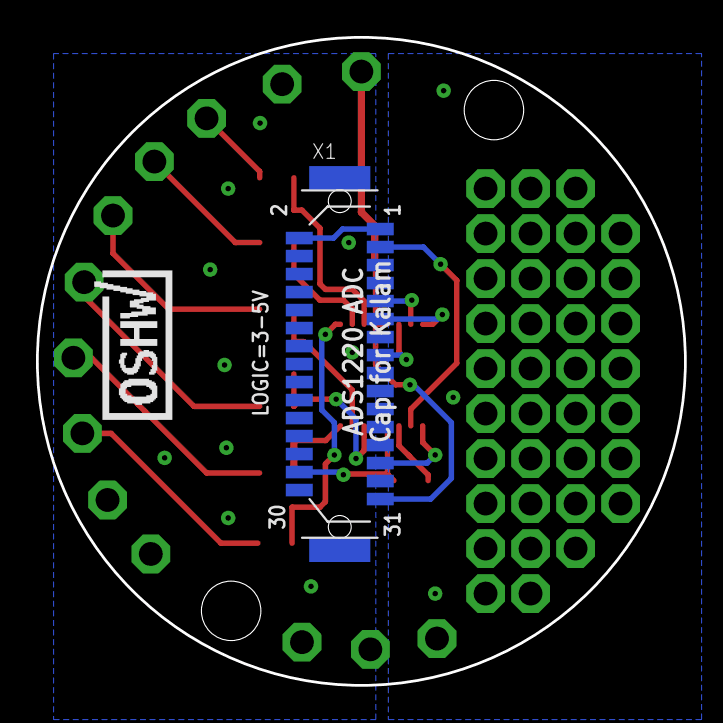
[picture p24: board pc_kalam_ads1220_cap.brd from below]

Board: 4 copper layers, 36.0 x 36.0 mm, 73 parts (4 on the bottom side), 21 nets.

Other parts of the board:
U$4: KALAM-NAME-ONLY

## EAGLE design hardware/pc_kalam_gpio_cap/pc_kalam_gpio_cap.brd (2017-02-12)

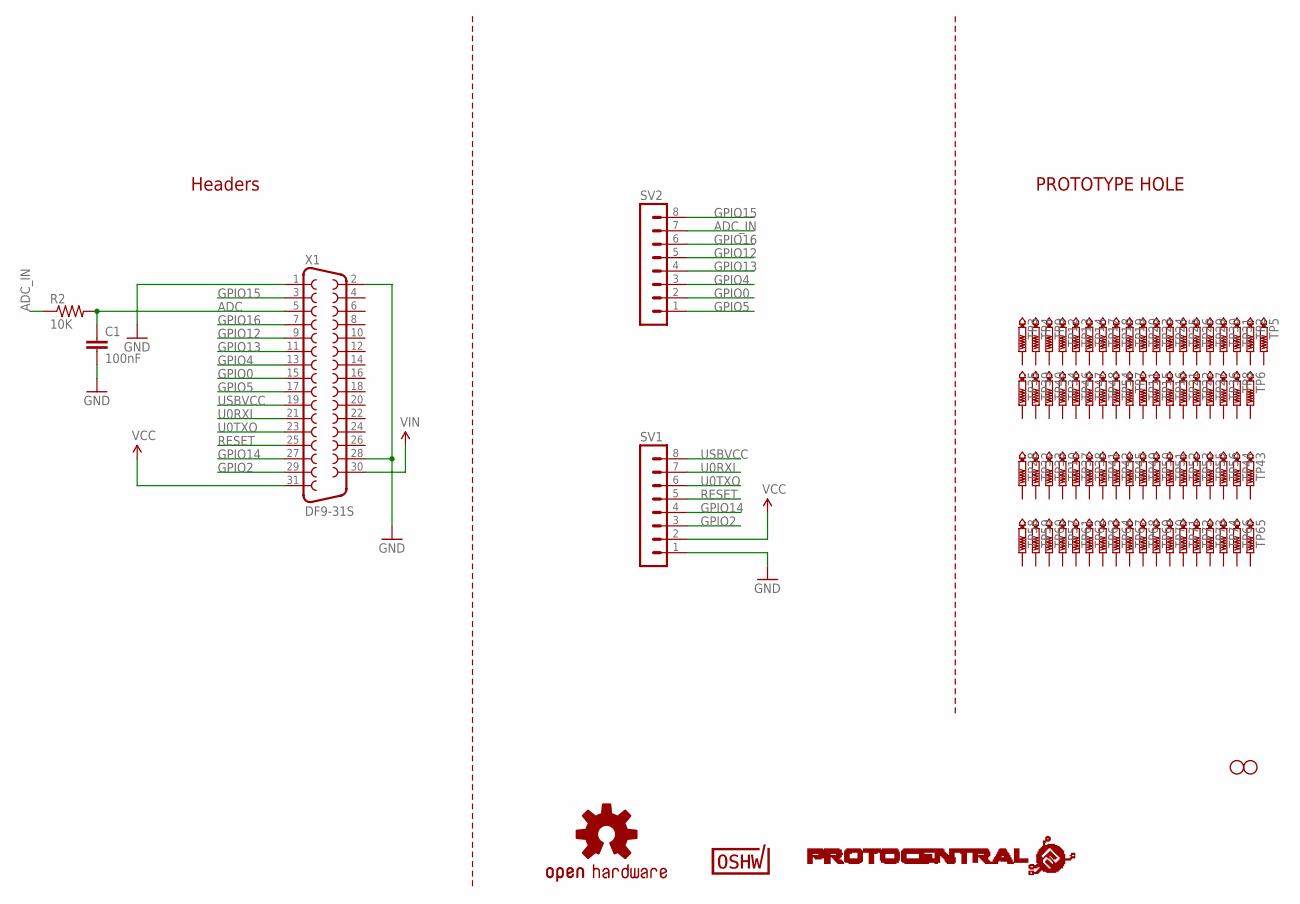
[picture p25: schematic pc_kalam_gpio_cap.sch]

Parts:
C1: 100nF; C0805
R2: 10K; R0805
STANDOFF7, STANDOFF8: STAND-OFF
SV1, SV2: MA08-1
TP2, TP3, TP4, TP5, TP6, TP7, TP8, TP9, TP10, TP11, TP12, TP13, TP14, TP15, TP16, TP17, TP18, TP19, TP20, TP21, TP22, TP23, TP24, TP25, TP26, TP27, TP28, TP29, TP30, TP31, TP32, TP33, TP34, TP35, TP36, TP37, TP38, TP39, TP40, TP41, TP42, TP43, TP44, TP45, TP46, TP47, TP48, TP49, TP50, TP51, TP52, TP53, TP54, TP55, TP56, TP57, TP58, TP59, TP60, TP61, TP62, TP63, TP64, TP65, TP66, TP67, TP68, TP69, TP70, TP71, TP72, TP73, TP74: PTR1PAD1-13; P1-13
U$2: CERT-SMALL; CERT-SMALL-SILK
U$3: OSHW-LOGOS; OSHW-LOGO-S
U$6: PROTY_LOGO_WITH_TEXT; PROTY_WITH_TEXT
X1: DF9-31S

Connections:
ADC: C1.1, R2.2, X1.5
ADC_IN: R2.1, SV2.7
GND: C1.2, SV1.1, X1.1, X1.2, X1.28
GPIO0: SV2.2, X1.15
GPIO2: SV1.3, X1.29
GPIO4: SV2.3, X1.13
GPIO5: SV2.1, X1.17
GPIO12: SV2.5, X1.9
GPIO13: SV2.4, X1.11
GPIO14: SV1.4, X1.27
GPIO15: SV2.8, X1.3
GPIO16: SV2.6, X1.7
RESET: SV1.5, X1.25
U0RXI: SV1.7, X1.21
U0TXO: SV1.6, X1.23
USBVCC: SV1.8, X1.19
VCC: SV1.2, X1.31
VIN: X1.30

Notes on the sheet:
Headers
PROTOTYPE HOLE

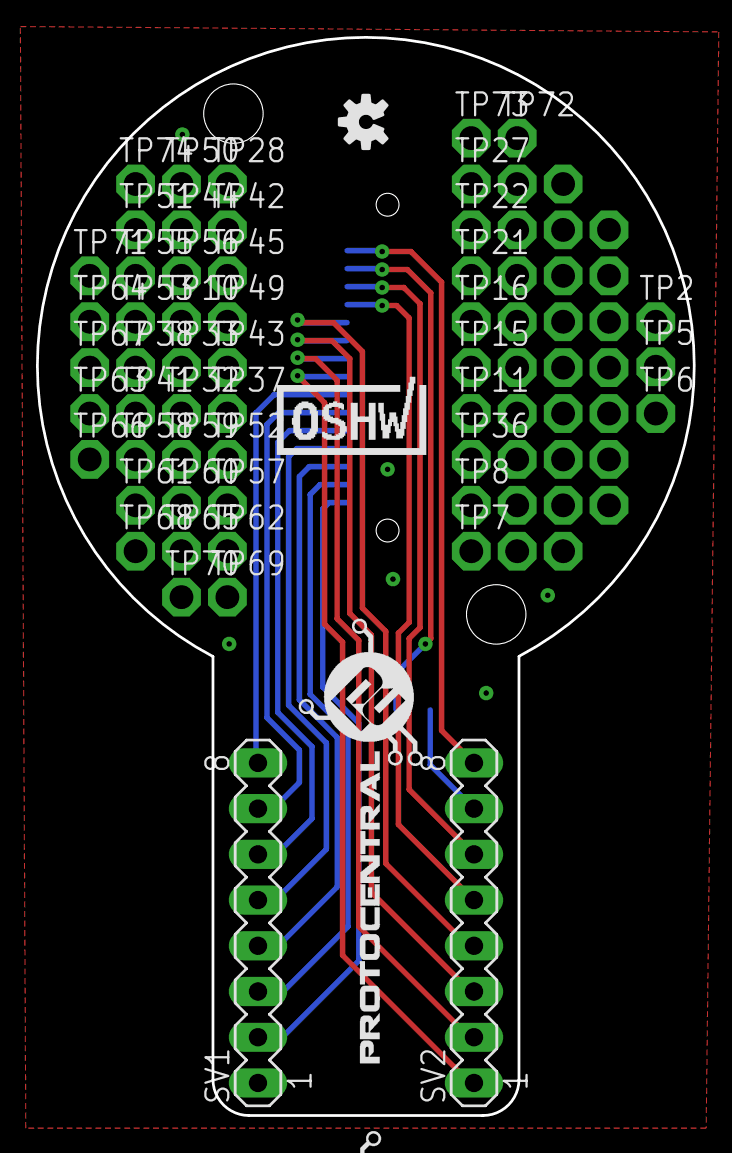
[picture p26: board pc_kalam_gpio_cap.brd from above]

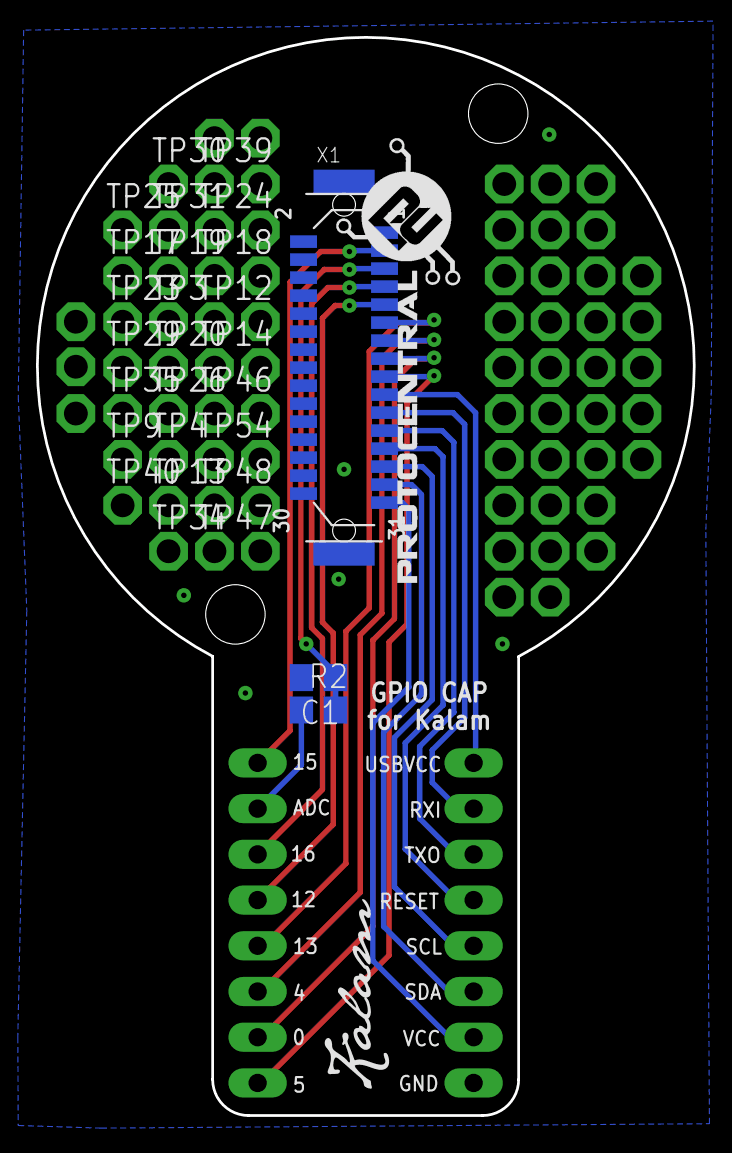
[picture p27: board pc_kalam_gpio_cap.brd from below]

Board: 4 copper layers, 36.5 x 59.9 mm, 86 parts (32 on the bottom side), 17 nets.

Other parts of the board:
U$1, U$5: PROTY_LOGO_WITH_TEXT; PROTY_WITH_TEXT
U$4: KALAM-NAME-ONLY

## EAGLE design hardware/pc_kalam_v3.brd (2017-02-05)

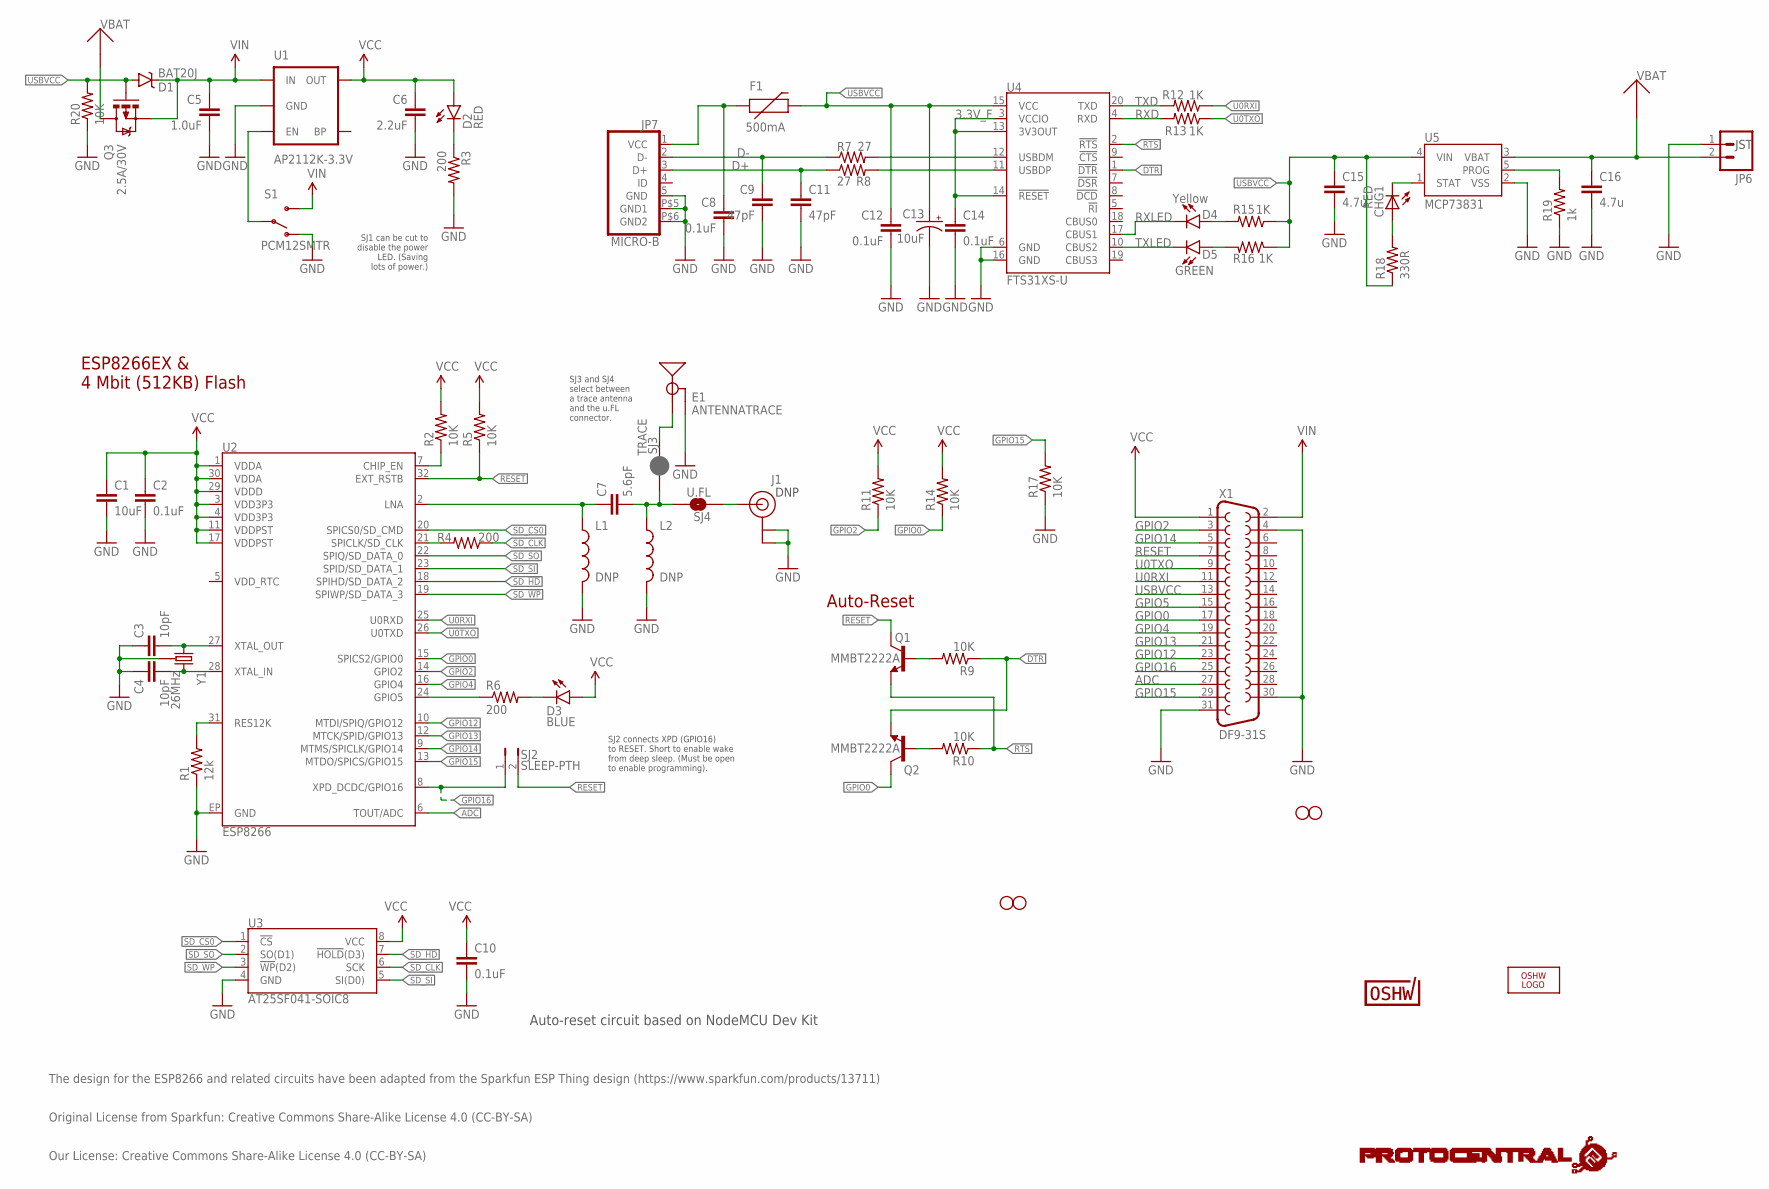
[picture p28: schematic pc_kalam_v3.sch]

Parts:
C1: 10uF; 0603-CAP
C2, C10, C12, C14: 0.1uF; 0603-CAP
C3, C4: 10pF; 0603-CAP
C5: 1.0uF; 0805
C6: 2.2uF; 0603-CAP
C7: 5.6pF; 0603-CAP
C8: 0.1uF; C0402
C9, C11: 47pF; 0603-CAP
C13: 10uF; EIA3216
C15, C16: 4.7u; C0805
CHG1: RED; CHIPLED_0603
D1: BAT20J; SOD-323
D2: RED; LED-0603
D3: BLUE; LED-0603
D4: Yellow; LED-0603
D5: GREEN; LED-0603
E1: ANTENNATRACE; TRACE_ANTENNA_2.4GHZ_25.7MM
F1: 500mA; PTC-1206
J1: DNP; U.FL
JP6: M02-JST-2MM-SMT; JST-2-SMD
JP7: MICRO-B
L1, L2: DNP; 0603
LOGO2: OSHW_LOGO_FILLX0200-NT; OSHW_FILLX200_NOTEXT
Q1, Q2: MMBT2222A; SOT23-3@1
Q3: 2.5A/30V; SOT23-3
R1: 12k; 0603-RES
R2, R5, R9, R10, R11, R14, R17: 10K; 0603-RES
R3, R4, R6: 200; 0603-RES
R7, R8: 27; 0603-RES
R12, R13, R15, R16: 1K; 0603-RES
R18: 330R; R0402
R19: 1k; R0402
R20: 10K; R0402
S1: PCM12SMTR; SWITCH-SPST-SMD-A
SJ2: SLEEP-PTH; PTH-JUMPER-2-NO_NO_SILK
SJ3: TRACE; PAD-JUMPER-2-NC_BY_PASTE_NO_SILK
SJ4: U.FL; PAD-JUMPER-2-NO_NO_SILK
STANDOFF1, STANDOFF2, STANDOFF3, STANDOFF4: STAND-OFF
U1: AP2112K-3.3V; SOT23-5
U2: ESP8266; QFN32
U3: AT25SF041-SOIC8; SO08
U4: FTS31XS-U; SSOP20_L
U5: MCP73831; SOT23-5
U$1: PROTY_LOGO_WITH_TEXT; PROTY_WITH_TEXT
U$5: CERT-MEDIUM; CERT-MED-SILK
U$8: PROTY-LOGO; LOGO-PROTY
X1: DF9-31S
Y1: 26MHz; CRYSTAL-SMD-3.2X2.5

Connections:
3.3V_F: C14.1, U4.3 (VCCIO), U4.13 (3V3OUT), U4.14 (!RESET)
ADC: U2.6 (TOUT/ADC), X1.27
ANT: J1.P$3 (SIGNAL), SJ4.1
CHIP_EN: R2.1, U2.7 (CHIP_EN)
D+: C11.1, JP7.3 (D+), R8.1
D-: C9.1, JP7.2 (D-), R7.1
DTR: Q2.2 (E), R9.1, U4.1 (!DTR)
GND: C1.2, C2.2, C3.1, C4.1, C5.2, C6.2, C8.2, C9.2, C10.2, C11.2, C12.2, C13.C (-), C14.2, C15.2, C16.2, E1.GND, E1.GND2 (GND), J1.P$1 (GND), J1.P$2 (GND), JP6.1, JP7.5 (GND), JP7.P$5 (GND1), JP7.P$6 (GND2), L1.2, L2.2, R1.1, R3.2, R17.1, R19.1, R20.1, S1.1 (O), U1.2 (GND), U2.EP (GND), U3.4 (GND), U4.6 (GND), U4.16 (GND), U5.2 (VSS), X1.4, X1.30, X1.31, Y1.2 (GND), Y1.4 (GND)
GPIO0: Q2.3 (C), R14.1, U2.15 (SPICS2/GPIO0), X1.17
GPIO2: R11.1, U2.14 (GPIO2), X1.3
GPIO4: U2.16 (GPIO4), X1.19
GPIO5: R6.1, U2.24 (GPIO5), X1.15
GPIO12: U2.10 (MTDI/SPIQ/GPIO12), X1.23
GPIO13: U2.12 (MTCK/SPID/GPIO13), X1.21
GPIO14: U2.9 (MTMS/SPICLK/GPIO14), X1.5
GPIO15: R17.2, U2.13 (MTDO/SPICS/GPIO15), X1.29
GPIO16: SJ2.1, U2.8 (XPD_DCDC/GPIO16), X1.25
LNA: C7.1, L1.1, U2.2 (LNA)
LNA2: C7.2, L2.1, SJ3.1, SJ4.2
unnamed: R1.2, U2.31 (RES12K)
unnamed: C4.2, U2.28 (XTAL_IN), Y1.3 (2)
unnamed: C3.2, U2.27 (XTAL_OUT), Y1.1
unnamed: R7.2, U4.12 (USBDM)
unnamed: Q1.1 (B), R9.2
unnamed: R8.2, U4.11 (USBDP)
unnamed: D5.A, R16.2
unnamed: D3.C, R6.2
unnamed: D4.A, R15.2
unnamed: D2.C, R3.1
unnamed: Q2.1 (B), R10.2
unnamed: CHG1.C, U5.1 (STAT)
unnamed: S1.2, U1.3 (EN)
unnamed: CHG1.A, R18.2
unnamed: R19.2, U5.5 (PROG)
RESET: Q1.3 (C), R5.1, SJ2.2, U2.32 (EXT_RSTB), X1.7
RTS: Q1.2 (E), R10.1, U4.2 (!RTS)
RXD: R13.2, U4.4 (RXD)
RXLED: D4.C, U4.17 (CBUS1)
SD_!HD!: U2.18 (SPIHD/SD_DATA_2), U3.7 (!HOLD!(D3))
SD_!WP!: U2.19 (SPIWP/SD_DATA_3), U3.3 (!WP!(D2))
SD_CLK: R4.1, U3.6 (SCK)
SD_CLK0: R4.2, U2.21 (SPICLK/SD_CLK)
SD_CS0: U2.20 (SPICS0/SD_CMD), U3.1 (!CS!)
SD_SI: U2.23 (SPID/SD_DATA_1), U3.5 (SI(D0))
SD_SO: U2.22 (SPIQ/SD_DATA_0), U3.2 (SO(D1))
TRACE_ANT: E1.ANT (SIGNAL), SJ3.2
TXD: R12.2, U4.20 (TXD)
TXLED: D5.C, U4.10 (CBUS2)
U0RXI: R12.1, U2.25 (U0RXD), X1.11
U0TXO: R13.1, U2.26 (U0TXD), X1.9
USBVCC: C12.1, C13.A (+), C15.1, D1.A, F1.2, Q3.1 (G), R15.1, R16.1, R18.1, R20.2, U4.15 (VCC), U5.4 (VIN), X1.13
VBAT: C16.1, JP6.2, Q3.3 (D), U5.3 (VBAT)
VCC: C1.1, C2.1, C6.1, C10.1, D2.A, D3.A, R2.2, R5.2, R11.2, R14.2, U1.5 (OUT), U2.1 (VDDA), U2.3 (VDD3P3), U2.4 (VDD3P3), U2.11 (VDDPST), U2.17 (VDDPST), U2.29 (VDDD), U2.30 (VDDA), U3.8 (VCC), X1.1
VIN: C5.1, D1.C, Q3.2 (S), S1.3 (S), U1.1 (IN), X1.2
VUSB: C8.1, F1.1, JP7.1 (VCC)

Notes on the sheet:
ESP8266EX & 4 Mbit (512KB) Flash
Auto-Reset
JST
SJ2 connects XPD (GPIO16) to RESET. Short to enable wake from deep sleep. (Must be open to enable programming).
SJ1 can be cut to disable the power LED. (Saving lots of power.)
DNP
Auto-reset circuit based on NodeMCU Dev Kit
SJ3 and SJ4 select between a trace antenna and the u.FL connector.
The design for the ESP8266 and related circuits have been adapted from the Sparkfun ESP Thing design (https://www.sparkfun.com/products/13711)
Original License from Sparkfun: Creative Commons Share-Alike License 4.0 (CC-BY-SA)
Our License: Creative Commons Share-Alike License 4.0 (CC-BY-SA)

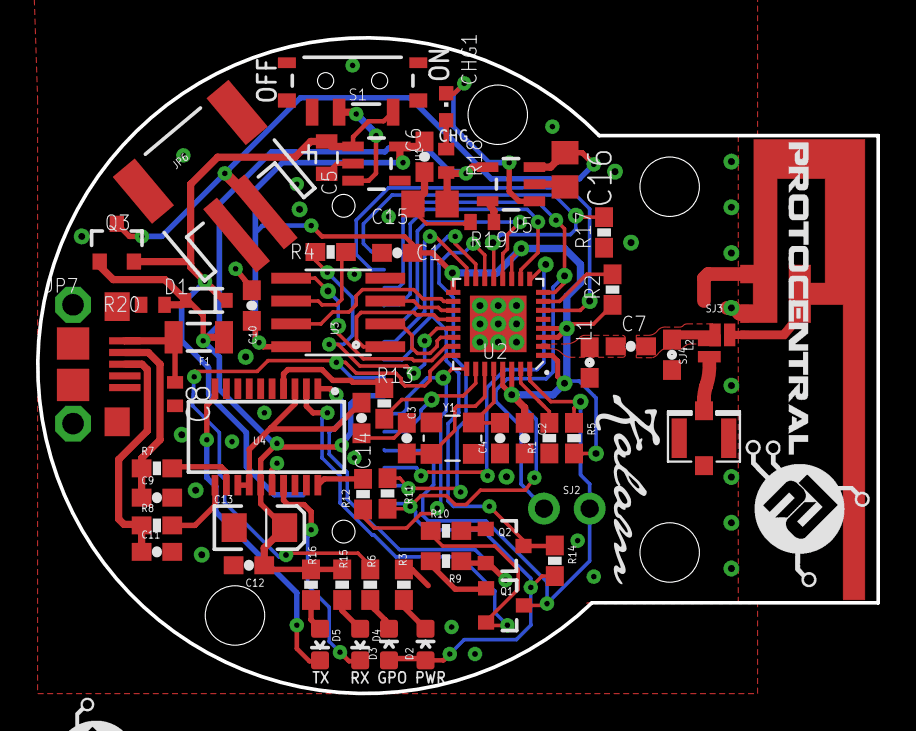
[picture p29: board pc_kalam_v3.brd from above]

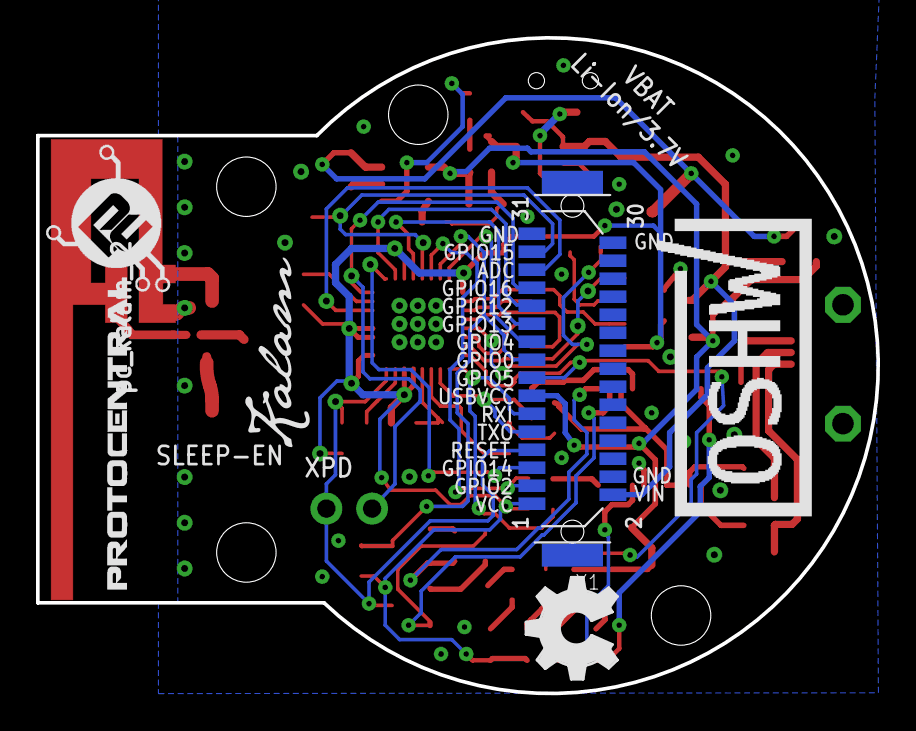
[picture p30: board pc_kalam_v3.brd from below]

Board: 4 copper layers, 46.7 x 36.4 mm, 74 parts (5 on the bottom side), 55 nets.

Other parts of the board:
U$2: PROTY_LOGO_WITH_TEXT; PROTY_WITH_TEXT
U$3, U$4: KALAM-NAME-ONLY

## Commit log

2017-02-12 Added design files for GPIO cap
    [pc_kalam_gpio_cap.brd, pc_kalam_gpio_cap.sch]
2017-02-12 Uploaded all cap designs
    [pc_kalam_ads1220_cap.brd, pc_kalam_ads1220_cap.sch, pc_kalam_sense_cap.brd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]

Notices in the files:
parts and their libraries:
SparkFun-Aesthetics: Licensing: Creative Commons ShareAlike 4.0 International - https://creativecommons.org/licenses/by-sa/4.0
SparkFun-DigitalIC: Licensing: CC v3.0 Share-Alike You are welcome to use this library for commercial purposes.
